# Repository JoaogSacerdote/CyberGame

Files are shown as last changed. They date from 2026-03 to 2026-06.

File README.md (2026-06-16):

# CyberGame — Console Educativo de Cibersegurança

> Console portátil de jogo educativo que ensina conceitos de segurança digital
> (senhas, backup, ransomware, DDoS) por meio de mecânicas de RPG top-down 2D
> em pixel art. Hardware próprio baseado em ESP32-S3.

**Versão:** 0.1.0 · **Plataforma:** ESP32-S3 + ESP-IDF 6.0 + LVGL 9.x

---

## Sobre o projeto

O CyberGame é um console portátil construído em hardware próprio. O jogador
assume o papel de um profissional de TI em uma empresa e precisa reagir a
ameaças digitais (ransomware, DDoS, propagação de malware) aplicando as
contramedidas corretas — backup, isolamento de rede, gestão de senhas — dentro
do tempo de um "expediente". O objetivo é ensinar os pilares de segurança da
informação de forma prática e lúdica.

---

## Hardware

| Componente | Descrição |
|---|---|
| **MCU** | ESP32-S3 (N16R8) com 8 MB PSRAM Octal @ 40 MHz |
| **Display** | LCD SPI ST7796, 480×320 px, backlight via transistor (GPIO 42) |
| **Entrada** | Joystick analógico (ADC) + 4 botões (A / B / X / Y) |
| **Armazenamento** | Cartão microSD via SPI (assets e layouts de sala) |
| **LEDs** | 3× WS2812 RGB (indicadores de tarefa) |
| **NFC** | Leitor PN532 via I²C (cartas físicas liberam ações no jogo) |

O pinout completo está em [`hardware/PINOUT.md`](hardware/PINOUT.md). Esquemas
elétricos e arquivos de PCB ficam em [`hardware/`](hardware/).

---

## Arquitetura do firmware

```
main/                 boot, banner e inicialização da engine
components/
  engine/             loop principal, init dos HALs, task LVGL
  hardware/           HALs: display, botões, joystick, PMU, SD, NFC
  hal_bridge/         ponte hardware → LVGL (HALs não conhecem LVGL)
  assets/             carregador de assets (cache load-once) e diálogos
  asset_store/        camada de arquivos sobre o storage
  entity/             pool de entidades, movimento, Y-sort, debug overlay
  ui/                 telas: splash, menu, recepção, empresa, HUD, pause
  fsm/                máquina de estados do jogo
  gamestate/          estado persistente (progresso, tarefas)
  recovery/           modo de recuperação via USB CDC
```

**Convenções principais:**
- HALs (`components/hardware/*.h`) nunca incluem LVGL — a integração fica em `hal_bridge/`.
- Atualizações de UI passam por *diff-gate* e usam `lv_timer_create` (não tasks FreeRTOS).
- Sistema de entidades com pivô *bottom-center*; ordenação por Y-sort.

---

## Compilando e gravando

Requer [ESP-IDF 6.0](https://docs.espressif.com/projects/esp-idf/) instalado.

```powershell
# Ativar o ambiente do ESP-IDF (PowerShell)
. "C:\esp\v6.0\esp-idf\export.ps1"

# Build + gravação + monitor serial
idf.py build flash monitor
```

> Se o build falhar com erros de paths/MinGW, apague a pasta `build/` e
> recompile.

---

## Pipeline de assets

Os sprites são desenhados como PNGs individuais e convertidos em blobs RGB565
prontos para o ESP32, gravados no cartão microSD. Os scripts ficam em
[`tools/`](tools/):

```powershell
# Gera os IDs de asset a partir do registry
python tools/gen_asset_ids.py

# Converte sprites + layouts para sdcard/assets/
python tools/build_sd_assets.py

# Copiar o conteúdo de sdcard/assets/ para o cartão microSD
```

A fonte de verdade dos assets é [`assets/asset_registry.json`](assets/asset_registry.json)
(nome → ID → arquivo). Os layouts de sala (posições das entidades) ficam em
`assets/layout/`.

---

## Estrutura do repositório

```
main/            ponto de entrada do firmware
components/      componentes do firmware (engine, HALs, UI, etc.)
assets/          sprites, diálogos, layouts e registry de assets
tools/           scripts do pipeline de assets e utilitários
hardware/        pinout, esquemas elétricos e arquivos de PCB
pc_simulator/    simulador das telas em PC (LVGL + SDL)
simulation/      simulação em PC (LVGL + SDL2)
test/            testes
```

---

## Simulador em PC

As telas de UI podem ser testadas no computador sem o hardware. Veja
[`pc_simulator/README.md`](pc_simulator/README.md) e
[`simulation/`](simulation/) para detalhes de compilação com LVGL + SDL.

---

## Status

Em desenvolvimento ativo (versão 0.1.0). Já funcionando: HALs de display,
botões, joystick, PMU e SD; engine com loop LVGL; pipeline de assets; sistema
de entidades com Y-sort; salas de recepção e empresa; FSM de estados.

---

## Autoria

Projeto desenvolvido por:

| Autor | E-mail | GitHub |
|---|---|---|
| **João Gabriel** | `joaog.souza2002@gmail.com` | [@JoaogSacerdote](https://github.com/JoaogSacerdote) |
| **Klayveer Silva** | `silvaklayveer@gmail.com` | [@Klayveer](https://github.com/Klayveer) |
| **Caio Godoy** | `caiogodoy05@gmail.com` | [@caiocodes](https://github.com/caiocodes) |

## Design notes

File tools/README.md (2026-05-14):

# tools/

Utilitarios de PC para conversar com o CyberGame em modo recovery via USB CDC.

## Pre-requisitos

```
pip install pyserial
```

## Como entrar em modo recovery no aparelho

1. Aparelho desligado.
2. Segure **PWR + REC** simultaneamente por 2 segundos.
3. Solte. Aparelho boota e enumera **uma porta serial nova** no PC (alem da porta UART/JTAG existente). Tipicamente aparece como "USB Serial Device" no Device Manager.

## Scripts

### test_ping.py

Smoke-test do protocolo de recovery (Fase 3). Monta um frame binario `CMD_PING`,
envia, e valida o `RESP_PONG` de volta — confirma enquadramento, CRC32 e o
round-trip USB CDC. O contrato do protocolo esta em
`components/recovery/include/recovery_proto.h`.

```
python test_ping.py COM21
```

Saidas possiveis:

| Saida | Significado |
|---|---|
| `OK — framing, CRC e round-trip USB CDC validados.` | Protocolo funcionando ponta a ponta |
| `FAIL: timeout esperando SOF ...` | ESP nao respondeu (2s) — checar se esta em recovery e se e a porta CDC certa |
| `FAIL: CRC do frame nao bate ...` | Resposta corrompida na linha — ruido ou bug de enquadramento |
| `FAIL: versao do firmware (vX) != script` | Firmware e script com versoes de protocolo diferentes — recompilar/atualizar |
| `<- NACK (esp_err_t = N)` | ESP rejeitou o comando — ver codigo de erro |
| `FAIL: nao consegui abrir a porta: ...` | Porta errada / outro programa segurando — checar Device Manager |

### asset_uploader.py

Gerencia os assets na NAND do aparelho via USB CDC. Subcomandos:

```
python tools/asset_uploader.py <PORTA> ping                        # PING -> PONG
python tools/asset_uploader.py <PORTA> ls                          # lista assets na NAND
python tools/asset_uploader.py <PORTA> upload                      # grava TODOS os assets do registry
python tools/asset_uploader.py <PORTA> upload rec_paredes          # grava so um asset
python tools/asset_uploader.py <PORTA> download sprite 0 piso.bin  # baixa o blob cru
python tools/asset_uploader.py <PORTA> download sprite 0 piso.png --png  # baixa e decodifica
python tools/asset_uploader.py <PORTA> erase sprite                # apaga uma categoria
python tools/asset_uploader.py <PORTA> reset                       # factory reset (tudo)
python tools/asset_uploader.py <PORTA> selftest                    # validacao fisica do NAND
```

`<tipo>` = `sprite` | `font` | `sound`. O `upload` e o `download --png` precisam
do Pillow (`pip install pillow`).

### recovery_protocol.py

Modulo (nao roda direto) com a camada de transporte do protocolo de recovery —
framing, CRC32 e a classe `RecoveryClient`. Espelha
`components/recovery/include/recovery_proto.h`. Importado por `test_ping.py` e
`asset_uploader.py`; fonte unica da logica de protocolo no lado PC.

### asset_codec.py

Modulo (nao roda direto) com o pipeline de imagem PNG -> RGB565/RGB565A8.
Espelha `components/assets/include/asset_blob.h`. Fonte unica do encoder —
usado tanto pelo `asset_uploader.py` (blobs da NAND) quanto pelo
`convert_assets.py` (arrays C embarcados, legado ate a Fase 6).

### gen_asset_ids.py

Gera `components/assets/include/asset_ids.h` a partir do registry — os
simbolos `ASSET_*` que o firmware usa com `asset_loader_load()`. Rode sempre
que mexer no `asset_registry.json`:

```
python tools/gen_asset_ids.py
```

## assets/asset_registry.json

Fonte unica de verdade dos assets: mapeia cada PNG renderizavel para um
`(type, id, name)` estavel. Consumido pelo `asset_uploader.py upload` (grava
na NAND) e pelo `gen_asset_ids.py` (gera os simbolos do firmware).
Arquivos `*_NULL.png` (mascaras de area/colisao) **nao** entram aqui.

## Identificando a porta CDC

No Windows: abre Device Manager → Portas (COM e LPT). Quando o aparelho entra em recovery, aparece uma porta nova. Geralmente "USB Serial Device (COMxx)".

Existem **duas portas** quando o aparelho esta em recovery:
- **Porta JTAG/UART** (para `idf.py monitor`) — aparece sempre quando aparelho ligado
- **Porta CDC** (para esses scripts) — so aparece em modo recovery

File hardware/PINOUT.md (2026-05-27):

# Pinout do CyberGame ESP32-S3

> Fonte de verdade: `components/hardware/include/board_pins.h`
> Última atualização: 2026-05-27

## Joystick analógico (ADC1)

| GPIO | Função | Notas |
|---|---|---|
| 1 | JOY_X | ADC1_CH0 |
| 2 | JOY_Y | ADC1_CH1 |

## Botões frontais

| GPIO | Função | Notas |
|---|---|---|
| 9 | BTN_A | input pull-up |
| 10 | BTN_X | input pull-up |
| 11 | BTN_B | input pull-up |
| 12 | BTN_Y | input pull-up |
| 13 | BTN_START | input pull-up; **dual-use com PMU_REC** |

## PMU (Power Management Unit)

| GPIO | Função | Notas |
|---|---|---|
| 13 | PMU_REC | recovery button; **mesmo pino do BTN_START** (PMU lê no boot, button_hal lê após) |
| 14 | PMU_PWR | power button + EXT0 wakeup |

## NFC PN532 (I2C)

| GPIO | Função | Notas |
|---|---|---|
| 4 | NFC_SCL | I2C clock |
| 39 | NFC_SDA | I2C data |
| 40 | NFC_IRQ | interrupt out |

## Display ST7796 (SPI2_HOST)

| GPIO | Função | Notas |
|---|---|---|
| 5 | DISP_CS | chip select |
| 6 | DISP_RST | reset ativo-baixo |
| 7 | DISP_DC | data/command select |
| 15 | DISP_MOSI | SPI MOSI; **compartilhado com NAND** |
| 16 | DISP_SCK | SPI clock; **compartilhado com NAND** |
| 17 | DISP_BL | backlight (LEDC PWM 10 kHz) |
| 42 | DISP_PWR_EN | NPN driver: 1=liga VCC, 0=corta |

## Storage NAND W25N01GV (SPI2_HOST, compartilha bus com display)

| GPIO | Função | Notas |
|---|---|---|
| 15 | NAND_MOSI | **mesmo pino do DISP_MOSI** |
| 16 | NAND_SCK | **mesmo pino do DISP_SCK** |
| 18 | NAND_MISO | exclusivo NAND |
| 41 | NAND_CS | chip select |

## Resumo por GPIO

| GPIO | Quem usa | Subsistema |
|---|---|---|
| 1 | JOY_X | Joystick |
| 2 | JOY_Y | Joystick |
| 4 | NFC_SCL | NFC |
| 5 | DISP_CS | Display |
| 6 | DISP_RST | Display |
| 7 | DISP_DC | Display |
| 9 | BTN_A | Botões |
| 10 | BTN_X | Botões |
| 11 | BTN_B | Botões |
| 12 | BTN_Y | Botões |
| 13 | BTN_START + PMU_REC | Botões + PMU (dual-use) |
| 14 | PMU_PWR | PMU |
| 15 | DISP_MOSI + NAND_MOSI | SPI2 (compartilhado) |
| 16 | DISP_SCK + NAND_SCK | SPI2 (compartilhado) |
| 17 | DISP_BL | Display |
| 18 | NAND_MISO | NAND |
| 39 | NFC_SDA | NFC |
| 40 | NFC_IRQ | NFC |
| 41 | NAND_CS | NAND |
| 42 | DISP_PWR_EN | Display |

## Invariantes garantidos por `_Static_assert` em board_pins.h

- `BOARD_PIN_BTN_START == BOARD_PIN_PMU_REC` (dual-use deliberado)
- `BOARD_PIN_NAND_MOSI == BOARD_PIN_DISP_MOSI` (bus SPI2 compartilhado)
- `BOARD_PIN_NAND_SCK == BOARD_PIN_DISP_SCK` (idem)

Mudar pino em `board_pins.h` sem respeitar esses invariantes quebra o build.

## Notas de hardware

- **Protoboard atual** (PCB descartada momentaneamente em 2026-05-27).
- **Bus SPI2 compartilhado**: Display é dono (`spi_bus_initialize`); NAND tolera `ESP_ERR_INVALID_STATE` e usa `spi_bus_add_device`.
- **Backlight do display** via LEDC channel 0, timer 0, duty 13-bit, freq 10 kHz.
- **Brownout Detector** ativo no nível 7 (max) — ver `sdkconfig` `CONFIG_BROWNOUT_DET_LVL=7`.
- Esquemático KiCad em `hardware/esquematico/` (referência visual).

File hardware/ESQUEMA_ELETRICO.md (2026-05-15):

# CyberGame — Informações para o Esquema Elétrico

> Console portátil **CyberSec: Network Defender**.
> Documento de referência para desenhar o schematic (KiCad em `hardware/CyberGame_kicad/`).
> Pinout confirmado pelo usuário; última revisão de GPIO em 2026-05-12.

---

## 1. Componentes principais

| Bloco | Componente | Interface | Tensão |
|---|---|---|---|
| MCU | **ESP32-S3 N16R8** (16 MB Flash, 8 MB PSRAM Octal) | — | 3V3 |
| Asset storage | **NAND SPI Winbond W25N01GV** (1 Gbit / 128 MB) | SPI | 3V3 |
| Display | **LCD TFT 4.0" 480x320**, controlador **ST7796S** | SPI 4-fios | 3V3 lógica + VCC painel |
| NFC | **PN532** (módulo) | I²C | 3V3 |
| Input analógico | Joystick analógico dual-axis (modelo PSP slim, **sem botão SEL**) | 2x ADC | 3V3 |
| Input digital | 4x push-button A/B/X/Y + REC/START + PWR | GPIO | 3V3 |
| Áudio | Buzzer **passivo** (piezo) | PWM | 3V3 |
| LEDs | **3x WS2812** endereçáveis | RMT 1-wire | 5V (ou 3V3, ver §7) |
| Energia | Bateria Li-Po + carregador **TP4056** + regulador 3V3 | — | 3.7–4.2 V → 3V3 |

⚠️ **GPIOs 26–37 são proibidos** — usados internamente pela PSRAM Octal. Não rotear nada neles.

---

## 2. Pinout definitivo do ESP32-S3

| GPIO | Função | Bloco | Observações |
|---|---|---|---|
| 1  | Joystick eixo X | ADC1_CH0 | Entrada analógica |
| 2  | Joystick eixo Y | ADC1_CH1 | Entrada analógica |
| 3  | **REC + START** (dual-use) | Botão | Boot: PMU lê como REC (combo PWR+REC = recovery). Pós-boot: BTN_START (pause). Ativo em nível baixo. |
| 4  | **PWR** | Botão | Botão de power/sleep. Fonte de wake `ext0` do Deep Sleep. Ativo em nível baixo. |
| 5  | NFC **SDA** | I²C | Precisa pull-up (ver §6) |
| 6  | NFC **SCL** | I²C | Precisa pull-up (ver §6) |
| 7  | **SPI MOSI** | SPI | **Compartilhado** Display + NAND |
| 8  | **SPI SCK** | SPI | **Compartilhado** Display + NAND |
| 9  | **MISO** | SPI | Usado pela NAND (leitura). Display é write-only. |
| 10 | NAND **CS** | SPI | Chip-select da NAND |
| 11 | Botão **A** | Botão | Confirmar / Interagir. Ativo em nível baixo. |
| 12 | Botão **B** | Botão | Cancelar / Voltar. Ativo em nível baixo. |
| 13 | Botão **X** | Botão | Dashboard do Analista. Ativo em nível baixo. |
| 14 | Botão **Y** | Botão | Abrir Terminal. Ativo em nível baixo. |
| 15 | **Buzzer** | PWM (LEDC) | Piezo passivo, acionamento direto. **Não** é strapping pin — escolha segura. |
| 16 | NFC **IRQ** | GPIO in | Interrupção do PN532 |
| 17 | Display **CS** | SPI | Chip-select do display |
| 18 | Display **DC** | GPIO out | Data/Command do ST7796S |
| 21 | Display **RST** | GPIO out | Reset do ST7796S |
| 38 | Display **BL** (LED do painel) | PWM (LEDC) | Pino LED/backlight do painel — controle de brilho |
| 42 | Display **VCC enable** | GPIO out | Liga/corta VCC do painel via transistor **NPN**. **1 = LIGA, 0 = CORTA** (ver §5) |
| 45 | *(livre)* | — | **Strapping pin** (VDD_SPI voltage) — deixar livre / não conectar. |
| 48 | **WS2812 Data** | RMT | Linha de dados dos 3 LEDs em cadeia |

**GPIOs livres / não usados:** 45 (strapping — não usar). Os demais não listados estão livres exceto 26–37 (PSRAM).

---

## 3. Barramento SPI (compartilhado: Display + NAND)

```
ESP32-S3  GPIO7  (MOSI) ──┬── ST7796S SDA/MOSI
                          └── W25N01GV DI (IO0)
ESP32-S3  GPIO8  (SCK)  ──┬── ST7796S SCK
                          └── W25N01GV CLK
ESP32-S3  GPIO9  (MISO) ───── W25N01GV DO (IO1)        (display não usa MISO)
ESP32-S3  GPIO17 (CS)   ───── ST7796S CS
ESP32-S3  GPIO10 (CS)   ───── W25N01GV CS
```

- Dois dispositivos, **um barramento**, **CS independentes** — só um ativo por vez.
- Display roda a 40 MHz; NAND a **50 MHz** (validado com `selftest`). A NAND suporta até ~104 MHz. O barramento é seguro pela seleção de CS.
- **Pull-up de ~10 kΩ em cada CS** (GPIO10 e GPIO17) para 3V3 — evita seleção espúria durante boot/reset, quando os GPIOs estão em alta impedância.
- Manter as trilhas MOSI/SCK curtas e de comprimento parecido; se possível, resistor série de 22–33 Ω em MOSI e SCK próximos ao ESP para conter ringing.
- W25N01GV: amarrar **WP#** e **HOLD#** a 3V3 (não usados no modo SPI single).

---

## 4. Barramento I²C (NFC PN532)

```
ESP32-S3  GPIO5 (SDA) ──┬── PN532 SDA ──── [4.7 kΩ] ── 3V3
ESP32-S3  GPIO6 (SCL) ──┬── PN532 SCL ──── [4.7 kΩ] ── 3V3
ESP32-S3  GPIO16      ───── PN532 IRQ
                          PN532 VCC ── 3V3
                          PN532 GND ── GND
```

- **Pull-ups obrigatórios**: 4.7 kΩ em SDA e SCL para 3V3 (se o módulo PN532 já trouxer pull-ups na placa, **não duplicar** — verificar antes).
- Confirmar que o módulo PN532 está com os jumpers/switch em modo **I²C** (muitos vêm em HSU/SPI de fábrica).
- IRQ é entrada — o firmware energiza o campo RF só quando necessário (estado de terminal). RST do PN532 pode ficar em 3V3 fixo se não for usado.

---

## 5. Display ST7796S — alimentação e controle

**Lógica (3V3):** CS=GPIO17, DC=GPIO18, RST=GPIO21, SCK=GPIO8, MOSI=GPIO7. MISO do display não é usado.

**Resumo da fiação de energia do display (confirmado pelo usuário):**
- **GPIO42** → base do transistor **NPN** → chave do **VCC do painel**.
- **GPIO38** → pino **LED/backlight** do painel (controle de brilho via PWM).

**VCC do painel — chave via GPIO42:**
- O GPIO 42 controla um **transistor NPN** que atua como *driver de gate* de uma chave high-side (P-MOSFET) que liga/desliga o **VCC do painel**.
- Polaridade lógica: **GPIO42 = 1 → painel LIGADO**; **GPIO42 = 0 → painel DESLIGADO**.
- Topologia recomendada:
  ```
  GPIO42 ──[1 kΩ]── base NPN ;  emissor NPN → GND
  coletor NPN ──┬── gate do P-MOSFET high-side
                └──[100 kΩ]── source/3V3 (pull-up do gate)
  P-MOSFET: source → 3V3 (ou rail do painel) ; dreno → VCC do display
  ```
  Com GPIO42=1 o NPN conduz, puxa o gate do P-MOSFET para baixo, e o P-MOSFET liga o VCC.
- ⚠️ O código de referência em `CONSULTA/display_hal.c` ainda usa lógica **PNP antiga** (0=liga). O hardware atual é **NPN (1=liga)** — substituído em 2026-05-10.
- Em boot: setar GPIO42=1 **antes** de iniciar o SPI e aguardar ~50 ms de estabilização.

**Backlight (BL = GPIO38):**
- Controlado por PWM (LEDC). Se o LED de backlight do painel exigir mais corrente do que um GPIO entrega com segurança (>20 mA), inserir um **transistor/MOSFET** para acionar o backlight, com o GPIO38 na base/gate. Verificar a corrente do backlight no datasheet do módulo do painel.

**Decoupling:** 100 nF + 10 µF próximos da alimentação do módulo do display.

---

## 6. Entradas digitais (botões)

6 botões momentâneos, todos **ativo-baixo** (botão entre GPIO e GND):

```
GPIO ──┬── botão ── GND
       └──[pull-up]── 3V3
```

- O ESP32-S3 tem **pull-up interno** — pode dispensar resistor externo. Para robustez (ruído/cabos longos), opcional pull-up externo de 10 kΩ.
- Debounce é feito em **firmware** (`button_hal`: ISR + timer). Opcional capacitor de 100 nF em paralelo com cada botão para debounce em hardware.
- Botões: A=11, B=12, X=13, Y=14, REC/START=3, PWR=4.
- **GPIO3 e GPIO4** são lidos pela PMU no boot (combo PWR+REC = modo recovery). GPIO4 também é a fonte de wake `ext0` do Deep Sleep — garantir que em repouso o pino fique em nível **alto** (pull-up) e o botão leve a **baixo**.

---

## 7. WS2812 (3 LEDs endereçáveis)

```
ESP32-S3 GPIO48 ──[330–470 Ω]── DIN do LED1 ── DOUT→DIN LED2 ── DOUT→DIN LED3
LEDs VCC ── 5V (ou 3V3, ver nota) ;  LEDs GND ── GND
Capacitor 1000 µF entre VCC e GND dos LEDs, próximo ao primeiro LED
```

- **Resistor série 330–470 Ω** na linha de dados, junto ao GPIO48.
- **Capacitor de bulk 1000 µF** (≥6.3 V) nos terminais de alimentação da fita/LEDs.
- **Alimentação: 3V3** (decisão confirmada pelo usuário). Os 3 LEDs são alimentados pelo próprio rail 3V3 do sistema — **sem level shifter**. Com VCC=3V3 o nível lógico "1" do ESP (3.3 V) atende o WS2812 sem margem problemática. Brilho levemente menor que a 5V, aceitável para 3 LEDs de status.
- Função: LED1 = tarefa verde pendente, LED2 = tarefa amarela, LED3 = alerta de ataque (lógica composta de escalada — ver `game_logic_decisions`).

---

## 8. Buzzer (áudio)

```
GPIO15 ──[resistor série opcional 100 Ω]── piezo ── GND
```

- **Pino escolhido: GPIO15.** Motivo: está livre, **não é strapping pin** e suporta PWM via LEDC. Substitui o GPIO45 sugerido antes — GPIO45 é strapping pin (VDD_SPI) e foi liberado.
- Buzzer **passivo** acionado por **PWM (LEDC)** direto do GPIO15 — **sem transistor** nesta versão (decisão de projeto).
- Só SFX, sem música de fundo. Mute = duty 0%.
- Se o volume ficar baixo, evoluir depois para um transistor + indutor/driver — mas **não** está no MVP.

---

## 9. Joystick analógico

Joystick dual-axis com 2 potenciômetros (um por eixo). **Sem botão SEL.**

```
Pot eixo X:  terminal1 → 3V3 ;  terminal2 → GND ;  wiper → GPIO1 (ADC1_CH0)
Pot eixo Y:  terminal1 → 3V3 ;  terminal2 → GND ;  wiper → GPIO2 (ADC1_CH1)
```

- Capacitor de **10–100 nF** de cada wiper para GND — filtra ruído do ADC.
- Usar **ADC1** (GPIO1/GPIO2 são ADC1) — ADC2 conflita com o Wi-Fi/rádio.
- Firmware faz média móvel (MA8) + deadzone 5% + calibração; mesmo assim o filtro RC em hardware ajuda.

---

## 10. Subsistema de energia

```
Li-Po 3.7V ──→ TP4056 (carga + proteção) ──→ Regulador 3V3 ──→ rail 3V3 do sistema
                    ↑
                USB 5V (carga)
```

- **TP4056**: módulo de carga Li-Po. Usar preferencialmente a versão **com proteção** (DW01 + FS8205) contra sobre-descarga/sobre-corrente.
- **Regulador 3V3**: a bateria entrega 3.0–4.2 V; o ESP32-S3 e todos os periféricos rodam em **3V3 regulado**. Opções:
  - **LDO** (ex.: AMS1117-3.3, ME6211, RT9013) — simples; escolher um que aguente o pico de corrente do ESP-S3 em TX (~500 mA de margem). O AMS1117 tem dropout alto (~1.1 V) — com a bateria abaixo de ~3.4 V o rail cai; preferir um LDO **low-dropout** (ME6211/RT9013, dropout ~0.25 V).
  - **Buck** se quiser maximizar autonomia.
- **Decoupling do ESP32-S3**: 100 nF em cada pino VDD + um bulk de 22–47 µF próximo ao módulo. Seguir as recomendações do datasheet do módulo ESP32-S3.
- **PWR / power management**: não há latch de hardware no MVP — o desligamento é via **Deep Sleep** do ESP, com wake por `ext0` no GPIO4. O botão PWR (GPIO4) só precisa de botão→GND + pull-up. (Se quiser desligamento real de hardware no futuro, adicionar um circuito de soft-latch com MOSFET.)
- Estimar a corrente de pico: ESP-S3 + backlight do display + 3 WS2812 podem somar facilmente >400 mA — dimensionar regulador e trilhas de alimentação para isso.

---

## 11. Checklist para o schematic

- [ ] ESP32-S3 N16R8 com decoupling completo (datasheet do módulo) e EN com RC de reset.
- [ ] Strapping pins: GPIO0 (boot), GPIO45/46 — **deixar livres** (GPIO45 não é mais usado pelo buzzer; buzzer migrou para GPIO15). GPIO3 também é strapping mas é uso intencional (REC).
- [ ] GPIOs 26–37 livres (PSRAM Octal).
- [ ] Pull-ups: I²C SDA/SCL (4.7k), SPI CS x2 (10k), botões (interno ou 10k).
- [ ] Barramento SPI com CS independentes; WP#/HOLD# da NAND em 3V3.
- [ ] Transistor NPN + P-MOSFET do VCC do display (GPIO42, lógica 1=liga).
- [ ] Resistor série + capacitor bulk dos WS2812; decidir alimentação 3V3.
- [ ] Filtro RC nos wibers do joystick; usar ADC1.
- [ ] TP4056 (com proteção) + regulador 3V3 low-dropout dimensionado para o pico.
- [ ] Conectores: USB (carga + dados/recovery CDC), bateria, display (FPC/header), módulo NFC, módulo joystick.
- [ ] Pontos de teste em 3V3, GND, MOSI, SCK, SDA, SCL.

---

## 12. Pendências / decisões em aberto de hardware

- **Backlight do display**: GPIO38 vai no pino LED do painel. Confirmar a corrente desse LED — define se GPIO38 aciona direto ou via MOSFET.
- **PN532**: confirmar se o módulo já tem pull-ups I²C na placa (para não duplicar) e se o modo está em I²C.
- Sem latch de power em hardware — desligamento só por Deep Sleep. Reavaliar se for requisito.

### Resolvidos
- ✅ **Buzzer**: GPIO15 (livre, não-strapping). GPIO45 liberado.
- ✅ **WS2812**: alimentação 3V3, sem level shifter.
- ✅ **GPIO42/38**: 42 = NPN do VCC do painel; 38 = pino LED/backlight. Lógica NPN (1=liga).

---

*Fontes: `hardware/PINOUT`, memória de projeto `project_hardware`, `game_logic_decisions` (RESPOSTAS.txt 2026-05-12), e código atual dos HALs em `components/hardware/`.*

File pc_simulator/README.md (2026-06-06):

# CyberSim — Simulador PC do firmware

Roda os mesmos `components/ui/screen_*.c` do firmware numa janela SDL no PC,
sem precisar flashar o aparelho a cada mudança visual.

## Estado atual

**Etapa 1** — Prova de conceito: SDL2 + LVGL 9.3.0 funcionando.
Ainda não integra os components do firmware.

| Etapa | Status |
|---|---|
| 1. Setup SDL + LVGL | ✅ |
| 2. HALs fake (joystick/botões via teclado) + FreeRTOS shim| ⏳ |
| 3. Storage fake (lê `nand.bin`) + asset_store + dialog | ⏳ |
| 4. Engine + FSM + telas do firmware compilando | ⏳ |

## Pré-requisitos

- MSYS2 instalado em `C:\msys64` com `mingw64/bin` (gcc, cmake, ninja, SDL2)
- Pacote: `pacman -S mingw-w64-x86_64-SDL2`

## Compilar e rodar

```bat
COMPILAR.bat
RODAR.bat
```

Resultado esperado da Etapa 1: janela 480×320 com fundo escuro e mensagem
"CyberSim — Etapa 1: pronto". Feche pra encerrar.

## Estrutura (futura)

```
pc_simulator/
  CMakeLists.txt           # build CMake usando SDL2 + MinGW
  main.c                   # app_main equivalente
  lv_conf.h                # config LVGL pra SDL (LV_COLOR_DEPTH=32, LV_USE_SDL=1)
  esp_idf_shim/            # esp_log, esp_err, esp_check, esp_heap_caps → stubs
  freertos_shim/           # xTaskCreate, xQueue, vTaskDelay → pthread
  hal_fake/                # display/joystick/button/nfc/pmu/storage fakes
  tools/                   # gerar nand.bin a partir do asset_registry.json
```

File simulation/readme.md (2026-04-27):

# CyberSec: Network Defender — Simulador LVGL (PC)

Simulador de PC do jogo embarcado **CyberSec: Network Defender**, escrito em C usando **LVGL 9.x**
renderizado via **SDL2**. Permite rodar e testar o jogo completo no Windows sem nenhum hardware real.

- Janela: **480 × 320 px** (equivalente ao display ILI9341 do ESP32-S3)
- Build: **CMake + MinGW GCC** via MSYS2
- Dependências externas: apenas SDL2 (já incluída no MSYS2)

---

## Estrutura do Projeto

```
simulation/
├── readme.md                       ← este arquivo
├── img/                            ← screenshots de referência (UI mockups)
└── lv_port_pc_eclipse/             ← projeto CMake para PC
    ├── main.c                      ← entry point: inicializa SDL + LVGL, chama cybersec_start()
    ├── cybersec_game.h             ← API pública do jogo
    ├── cybersec_game.c             ← motor completo (UI, FSM, lógica, ~1500 linhas)
    ├── lv_conf.h                   ← configuração LVGL (fontes, cores, resolução)
    ├── CMakeLists.txt              ← build system
    ├── COMPILAR.bat                ← compila o projeto (git submodule + cmake)
    ├── RODAR.bat                   ← inicia o executável com DLLs corretas
    ├── lvgl/                       ← biblioteca LVGL 9.3 (clonada pelo COMPILAR.bat)
    └── bin/
        └── main.exe                ← executável final (gerado após build)
```

---

## Pré-requisitos

| Ferramenta | Versão mínima | Observação |
|---|---|---|
| Windows | 10 / 11 | — |
| Git | qualquer | Para clonar o submodule LVGL |
| MSYS2 (GCC + CMake + SDL2) | — | Instalar antes de compilar |

### Instalar MSYS2 (apenas na primeira vez)

```bat
winget install --id MSYS2.MSYS2 --accept-package-agreements --accept-source-agreements
```

### Instalar GCC, CMake e SDL2 (apenas na primeira vez)

```bat
C:\msys64\usr\bin\pacman.exe -S --noconfirm --needed ^
  mingw-w64-x86_64-gcc ^
  mingw-w64-x86_64-cmake ^
  mingw-w64-x86_64-SDL2 ^
  mingw-w64-x86_64-make
```

---

## Como Compilar e Rodar

Navegue até `simulation/lv_port_pc_eclipse/` e:

### Primeira vez (ou após alterar o código)

Dê **duplo clique** em `COMPILAR.bat`. O script:

1. Verifica GCC/CMake em `C:\msys64\mingw64\bin\`
2. Clona o submodule LVGL via `git submodule update --init --recursive`
3. Executa `cmake -B build -S . -G "MinGW Makefiles"`
4. Compila com `cmake --build build --parallel 4`
5. Gera `bin/main.exe`

### Rodar

Dê **duplo clique** em `RODAR.bat`. A janela **480×320** abre imediatamente.

### Resumo rápido

```
1ª vez:  COMPILAR.bat  →  RODAR.bat
Demais:  RODAR.bat
Após editar código:  COMPILAR.bat  →  RODAR.bat
```

---

## Fluxo do Jogo

```
Tela Inicial
    │  [A] para iniciar
    ▼
Tutorial (8 passos)
    │  [A] para avançar cada diálogo
    ▼
Jogo (08:00 → 18:00)
    │  Resolver incidentes, mover entre salas
    ▼
Vitória (18:00 com integridade > 0)
ou Derrota (integridade chegou a 0)
    │  [R] para reiniciar
    ▼
  Tela Inicial
```

---

## Controles

| Tecla | Ação |
|---|---|
| `↑` `↓` `←` `→` | Mover o personagem pelo escritório |
| `A` ou `SPACE` | Confirmar diálogo de tutorial / Abrir e resolver incidente verde ou amarelo |
| `N` | Scan NFC — abre e resolve incidente vermelho (Ransomware) |
| `R` | Reiniciar o jogo a qualquer momento |

### Resolver um incidente

1. Mova o personagem **até ficar próximo** da bolha colorida no mapa (raio ~50 px).
2. Pressione `A` (incidentes verdes ou amarelos) ou `N` (ransomware vermelho).
3. Um **diálogo de detalhe** abre com informações da vulnerabilidade.
4. Pressione `A` ou `N` novamente para confirmar a resolução.

---

## Mecânicas do Jogo

### Mapa — Dois Andares

O jogo possui dois ambientes com layout pixel-art:

```
┌─────────────────────────────────────┐
│         Recepção (Sala 1)           │  ── porta direita ──►  Escritório
│  (prateleiras, tapete, sofá, rack)  │
└─────────────────────────────────────┘

┌─────────────────────────────────────┐
│         Escritório (Sala 2)         │  ◄── porta esquerda ── Recepção
│  (mesas, PCs, impressoras, plantas) │
└─────────────────────────────────────┘
```

**Transição entre salas:** caminhe até a **borda lateral** (indicador `► 2` ou `◄ 1`).  
O personagem aparece na porta oposta da outra sala.

---

### Incidentes (Bolhas Coloridas)

A cada 9–16 segundos, um incidente surge em ponto fixo de uma sala aleatória:

| Ícone | Cor | Tipo | Drenagem | Resolução | Pontos |
|---|---|---|---|---|---|
| `?` | Verde | Tarefa de prevenção | 1 HP/2s | `A` / `SPACE` | +15 |
| `!` | Amarelo | Anomalia suspeita | 4 HP/2s | `A` / `SPACE` | +15 |
| `X` | Vermelho | Ransomware ativo | 10 HP/2s | `N` (NFC scan) | +30 |

Máximo de **4 incidentes simultâneos** em toda a empresa.

---

### Sistema de Integridade da Rede

- Exibida no HUD como barra colorida e percentual.
- Calculada a partir dos HP dos incidentes ativos:
  - Sem incidentes ativos → **100%**
  - Com incidentes → proporcional ao HP médio restante
- Cor da barra: verde (>60%), amarelo (>30%), vermelho (≤30%).
- **Integridade = 0% → Derrota imediata.**

---

### Relógio do Jogo

- **3 minutos reais** = expediente completo das **08:00 às 18:00** (10h de jogo).
- O relógio aparece no canto superior esquerdo do HUD.
- Chegar às **18:00** com integridade > 0 = **Vitória**.

---

### Tutorial

Ao iniciar, o NPC guia apresenta **8 diálogos** explicando:

1. Boas-vindas e contexto do jogo
2. Controles de movimento
3. Incidentes verdes (prevenção)
4. Incidentes amarelos (anomalias)
5. Incidentes vermelhos (ransomware)
6. Como interagir com incidentes
7. Consequências de ignorar incidentes
8. Dica sobre explorar as duas salas

Pressione `A` para avançar cada passo.

---

## Arquitetura do Código

```
main.c
├── hal_init(480, 320)               — cria display SDL 480×320, registra driver LVGL
├── SDL_AddEventWatch(sdl_key_watch) — hook de teclado SDL → cybersec_sdl_key_event()
└── loop: lv_timer_handler() + SDL_Delay(5)

cybersec_start()                     — inicializa estado global, cria tela inicial
    │  [A]
    ▼
create_hud()                         — barra HUD: relógio, REDE: [barra], status
build_room1() / build_room2()        — layout pixel-art com lv_obj (mk_rect calls)
create_player()                      — personagem: head (skin+hair) + body (camisa)
show_tutorial_step()                 — overlay com portrait NPC + texto + indicador [A] N/8
    │  após step 8
    ▼
start_timers()
    ├── tmr_move_cb   (16 ms)   — move personagem, detecta transição de sala
    ├── tmr_clock_cb  (500 ms)  — avança relógio do jogo, checa vitória às 18:00
    ├── tmr_event_cb  (9–16 s)  — sorteia sala + tipo de incidente, cria bolha colorida
    └── tmr_drain_cb  (2 s)     — drena HP dos incidentes ativos, checa derrota

cybersec_sdl_key_event(key, pressed)
    ├── UP/DOWN/LEFT/RIGHT  → g_keys.* lidas por tmr_move_cb
    ├── A / SPACE           → avança tutorial ou abre/resolve dialog de incidente
    ├── N                   → abre/resolve dialog de ransomware (NFC)
    └── R                   → do_restart() — limpa tudo e reinicia
```

---

## Integração com Firmware ESP32 (Wokwi / Hardware Real)

O motor do jogo (`cybersec_game.c`) **não depende de SDL**, apenas de LVGL.  
Para rodar no ESP32-S3 com ILI9341:

1. Adicione `cybersec_game.h` e `cybersec_game.c` ao componente `main/` do projeto ESP-IDF.
2. No `app_main()`, após inicializar o driver LVGL:
   ```c
   cybersec_start();
   ```
3. No handler de botões/joystick (FreeRTOS task), chame:
   ```c
   cybersec_sdl_key_event(SDLK_UP, true);    // botão pressionado
   cybersec_sdl_key_event(SDLK_UP, false);   // botão solto
   ```

> Os valores `SDLK_*` são `#define` numéricos no topo de `cybersec_game.c`.  
> No ESP-IDF, mapeie os GPIOs dos botões para esses mesmos valores.

---

## Extensões Sugeridas

- [ ] Tileset real com `lv_image` (bitmap pixel-art exportado como C array)
- [ ] Animação do personagem ao caminhar (`lv_anim` no frame do sprite)
- [ ] Som via buzzer PWM no ESP32 ao detectar ransomware (`ledc_set_freq`)
- [ ] Placar persistente em NVS (ESP32) ou arquivo local (PC)
- [ ] Terceira sala — Sala de Servidores — com eventos críticos de maior frequência
- [ ] Barra de stamina do analista (uso excessivo de NFC cansa o personagem)

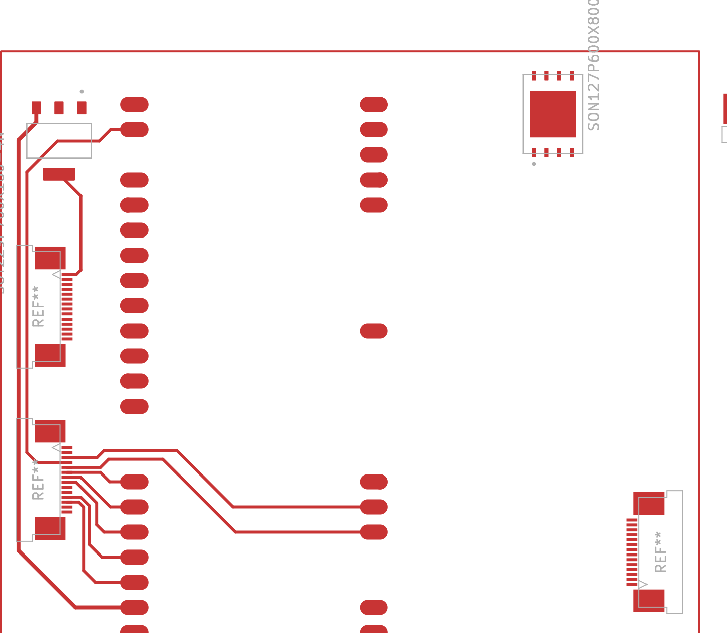
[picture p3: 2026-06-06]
hardware/pcb/PCB/_view_esp.png

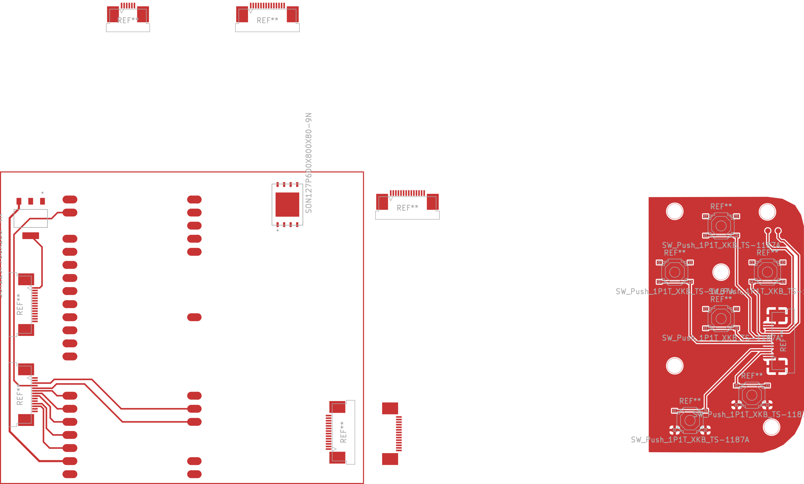
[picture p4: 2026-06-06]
hardware/pcb/PCB/_view_full.png

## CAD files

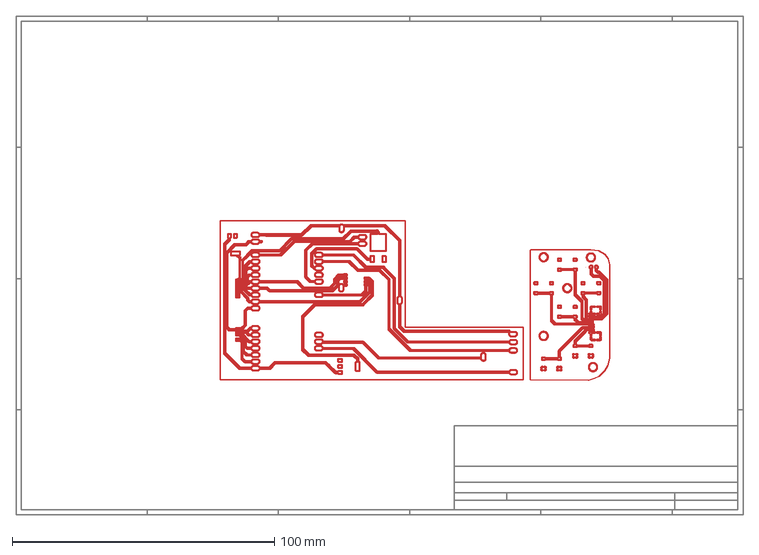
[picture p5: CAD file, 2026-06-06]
hardware/pcb/PCB/PCB.dxf
277.0 x 190.0 mm

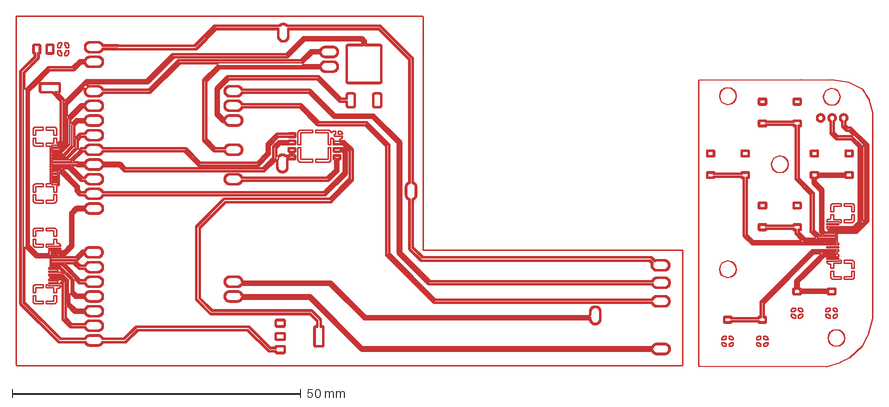
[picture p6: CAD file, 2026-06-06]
hardware/pcb/PCB/PCB-F_Cu.dxf
148.4 x 60.7 mm

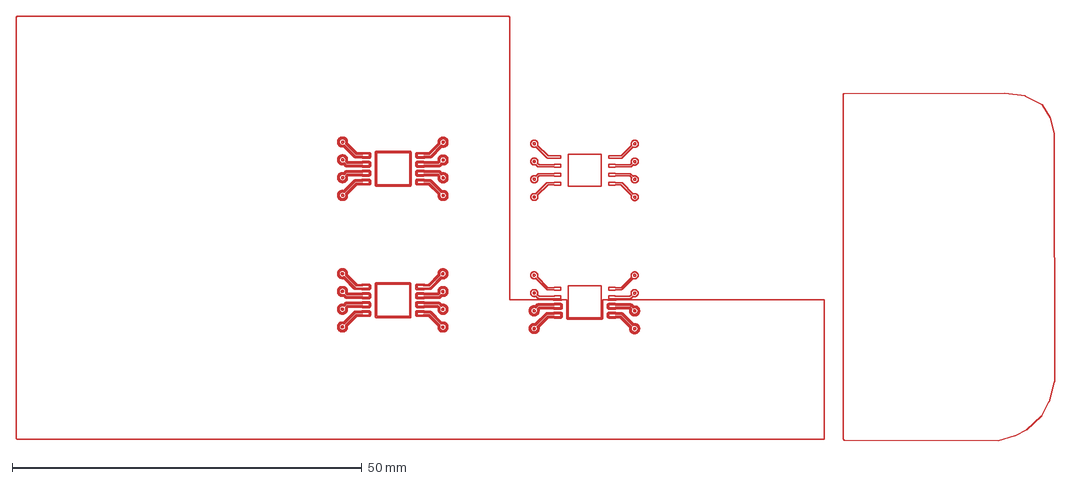
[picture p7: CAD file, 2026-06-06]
hardware/pcb/PCB/PCB.kicad_pcb_pads-F_Cu.dxf
148.4 x 60.7 mm

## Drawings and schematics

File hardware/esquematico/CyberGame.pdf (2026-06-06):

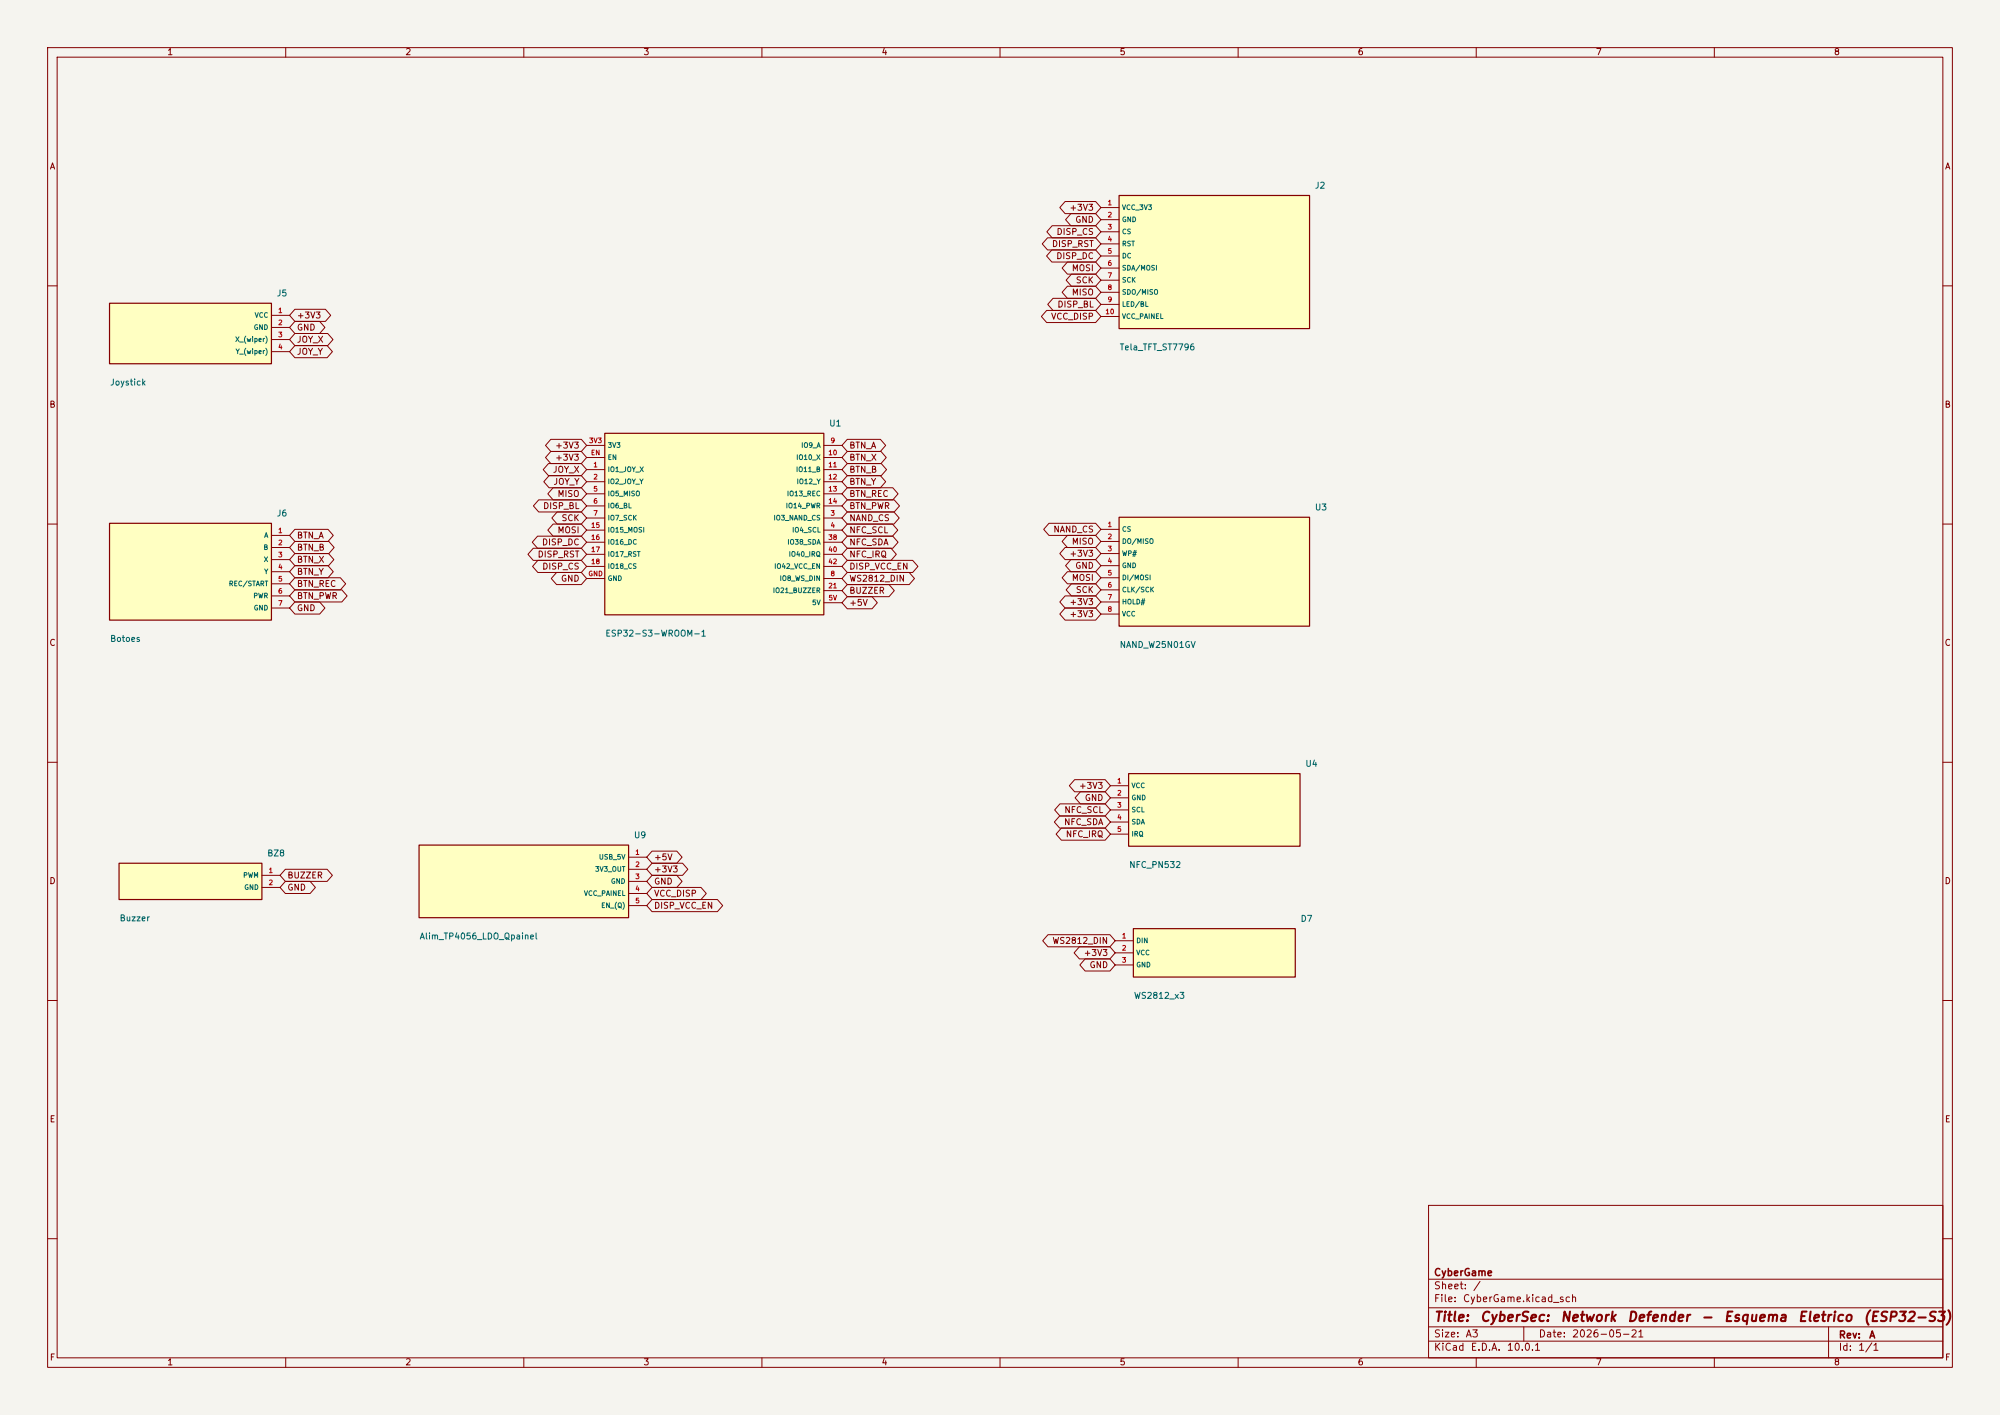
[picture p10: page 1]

CyberGame
Sheet: /
File: CyberGame.kicad_sch
Title: CyberSec: Network Defender - Esquema Eletrico (ESP32-S3)

Size: A3 | Rev: A | F Date: 2026-05-21
KiCad E.D.A. 10.0.1 | Id: 1/1

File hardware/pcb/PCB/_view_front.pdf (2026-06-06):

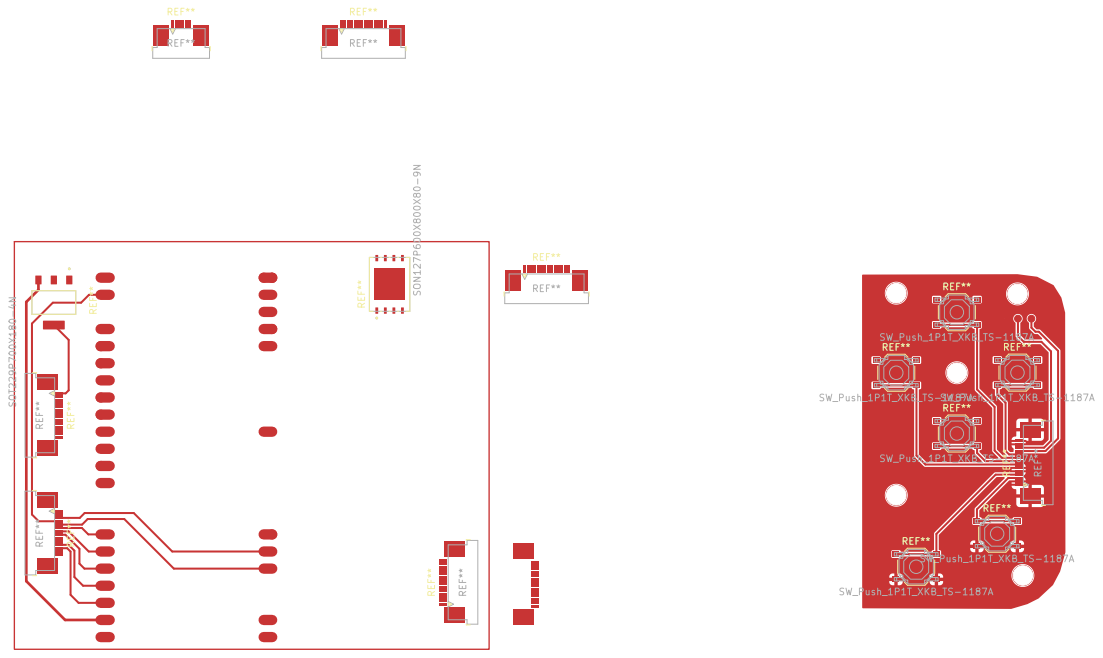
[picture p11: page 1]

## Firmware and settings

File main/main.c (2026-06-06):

#include <stdint.h>
#include <stdio.h>
#include "freertos/FreeRTOS.h"
#include "freertos/task.h"
#include "esp_idf_version.h"
#include "esp_log.h"
#include "esp_system.h"

#include "version.h"
#include "pmu.h"
#include "button_hal.h"
#include "joystick_hal.h"
#include "nfc_hal.h"
#include "display_hal.h"
#include "ws2812_hal.h"
#include "buzzer_hal.h"
#include "sd_hal.h"
#include "hal_bridge.h"
#include "ui_debug.h"     /* modo dev — acessivel pelo combo Y+START */
#include "engine.h"       /* gameplay loop */

static const char *TAG = "APP_MAIN";

/* ===== MODO DE TESTE REMOTO (mude SO este numero entre 1 e 0) ==============
 * 1 = BYPASSA o botao PWR (boota direto em NORMAL) + LIGA o jogador-fantasma
 *     (task que joga sozinha e loga tudo no console). Para testar sem o
 *     hardware fisico.
 * 0 = comportamento normal: segura PWR pra ligar, sem fantasma (producao).
 * ========================================================================== */
#define DEV_TEST_MODE   0

#define DEV_COMBO_POLL_MS   100
#define DEV_COMBO_HOLD_MS   2000

/* Combo dev: Y + START ja pressionados ao entrar em detect_dev_combo
 * e segurados continuamente por DEV_COMBO_HOLD_MS -> entra em ui_debug.
 * Caso contrario retorna imediatamente.
 *
 * Detecta assim que main.c termina os inits — o usuario pode comecar a
 * segurar o combo durante o splash anterior do PMU e ainda pegar. */
#if !DEV_TEST_MODE
static bool detect_dev_combo(void)
{
    if (button_hal_peek(BTN_Y) != BTN_PRESSED ||
        button_hal_peek(BTN_START) != BTN_PRESSED) {
        return false;
    }
    ESP_LOGI(TAG, "Combo dev Y+START detectado. Segure por %d ms para confirmar.",
             DEV_COMBO_HOLD_MS);
    for (int waited = 0; waited < DEV_COMBO_HOLD_MS; waited += DEV_COMBO_POLL_MS) {
        if (button_hal_peek(BTN_Y) != BTN_PRESSED ||
            button_hal_peek(BTN_START) != BTN_PRESSED) {
            ESP_LOGI(TAG, "Combo desfeito antes dos %d ms. Seguindo boot normal.",
                     DEV_COMBO_HOLD_MS);
            return false;
        }
        vTaskDelay(pdMS_TO_TICKS(DEV_COMBO_POLL_MS));
    }
    return true;
}
#endif /* !DEV_TEST_MODE */

static const char *reset_reason_name(esp_reset_reason_t r)
{
    switch (r) {
        case ESP_RST_POWERON:    return "POWERON";
        case ESP_RST_EXT:        return "EXT";
        case ESP_RST_SW:         return "SW";
        case ESP_RST_PANIC:      return "PANIC";
        case ESP_RST_INT_WDT:    return "INT_WDT";
        case ESP_RST_TASK_WDT:   return "TASK_WDT";
        case ESP_RST_WDT:        return "OTHER_WDT";
        case ESP_RST_DEEPSLEEP:  return "DEEPSLEEP_WAKE";
        case ESP_RST_BROWNOUT:   return "BROWNOUT";
        case ESP_RST_SDIO:       return "SDIO";
        default:                 return "UNKNOWN";
    }
}

static void log_boot_banner(void)
{
    const esp_reset_reason_t r = esp_reset_reason();
    ESP_LOGI(TAG, "======================================================");
    ESP_LOGI(TAG, "  CyberGame v" CYBERGAME_VERSION_STR " (idf %s)", IDF_VER);
    ESP_LOGI(TAG, "  reset reason: %s", reset_reason_name(r));
    ESP_LOGI(TAG, "======================================================");
}

void app_main(void)
{
    log_boot_banner();

    ESP_ERROR_CHECK(pmu_init());

#if DEV_TEST_MODE
    /* BYPASS: forca boot NORMAL sem segurar PWR (teste remoto). Pula o latch
     * e o monitor de shutdown (evita deep sleep acidental com PWR flutuando). */
    ESP_LOGW(TAG, "[DEV] DEV_TEST_MODE=1 — PMU latch BYPASSADO (boot NORMAL forcado)");
    const pmu_boot_mode_t mode = PMU_BOOT_NORMAL;
#else
    ESP_LOGI(TAG, "Avaliando Power Latch...");
    const pmu_boot_mode_t mode = pmu_check_boot_mode();

    if (mode == PMU_BOOT_ABORT) {
        ESP_LOGW(TAG, "Botao solto prematuramente. Voltando ao Deep Sleep.");
        pmu_enter_deep_sleep();
    }

    /* Monitor de PWR para shutdown (hold longo -> deep sleep). */
    xTaskCreate(pmu_shutdown_monitor_task, "pmu_monitor", 3072, NULL, 5, NULL);
#endif

    /* PMU_BOOT_NORMAL daqui em diante. */
    ESP_LOGI(TAG, "Boot NORMAL confirmado! Iniciando sistema...");

    /* ============================================================
     * === MODO BRING-UP TEMPORARIO (2026-05-26) — INICIO ===
     * Todos os HALs de hardware aqui tolerantes a falha: log + segue.
     * Para reverter: ver CyberGameCore/CHANGELOG/entries/2026-05-26T1945-bring-up-mode-completo.md
     * Bloco original preservado integralmente nessa entrada.
     * ============================================================ */

    if (button_hal_init() != ESP_OK) {
        ESP_LOGW(TAG, "[BRING-UP] buttons ausentes — boot continua sem input de botoes.");
    }
    if (joystick_hal_init() != ESP_OK) {
        ESP_LOGW(TAG, "[BRING-UP] joystick ausente — boot continua sem ADC do analog.");
    }
    if (nfc_hal_init() != ESP_OK) {
        ESP_LOGW(TAG, "[BRING-UP] NFC ausente — boot continua sem leitura de cartao.");
    }
    if (ws2812_hal_init() != ESP_OK) {
        ESP_LOGW(TAG, "[BRING-UP] WS2812 ausente — boot continua sem LEDs de feedback.");
    } else {
        /* Diagnostico de hardware: 3 LEDs em vermelho por 300 ms.
         * Se nao acender visivelmente, o driver iniciou mas a eletrica
         * (alimentacao/GND/GPIO 8/data line) tem problema. Remover apos
         * confirmar que a tira responde. */
        ws2812_hal_set_all(80, 0, 0);
        ws2812_hal_refresh();
        vTaskDelay(pdMS_TO_TICKS(300));
        ws2812_hal_clear();
        ws2812_hal_refresh();
    }
    if (buzzer_hal_init() != ESP_OK) {
        ESP_LOGW(TAG, "[BRING-UP] buzzer ausente — boot continua sem SFX.");
    }

    /* Display: sem ele nao tem como rodar LVGL/engine/ui_debug. Marca flag. */
    bool ui_ok = true;
    if (display_hal_init() != ESP_OK) {
        ESP_LOGW(TAG, "[BRING-UP] display ausente — boot continua mas sem video.");
        ui_ok = false;
    } else if (hal_bridge_init() != ESP_OK) {
        ESP_LOGW(TAG, "[BRING-UP] hal_bridge falhou — boot continua mas sem UI.");
        ui_ok = false;
    } else {
        display_hal_set_backlight_percent(70);
    }

    /* microSD (slot do modulo de display). O barramento SPI2 ja foi inicializado
     * pelo display acima. Fase 1: so detectar/montar e listar a raiz. Tolerante:
     * se falhar, boot segue (as telas ficam sem assets ate a migracao Fase 2). */
    if (sd_hal_init() != ESP_OK) {
        ESP_LOGW(TAG, "[BRING-UP] microSD ausente — boot continua sem storage.");
    } else {
        sd_hal_list_root();
        sd_hal_selftest();   /* valida escrita+leitura do cartao */
    }

    /* Sem UI nao tem como rodar engine nem ui_debug (ambos chamam LVGL).
     * Idle com heartbeat de 5s pra deixar UART respirar e mostrar que vive. */
    if (!ui_ok) {
        ESP_LOGW(TAG, "[BRING-UP] UI indisponivel — pulando engine/ui_debug. Heartbeat a cada 5s.");
        while (1) {
            ESP_LOGW(TAG, "[BRING-UP] alive — sem UI");
            vTaskDelay(pdMS_TO_TICKS(5000));
        }
    }

#if !DEV_TEST_MODE
    /* Combo dev: Y+START segurados juntos por 2s -> ui_debug.
     * Caso contrario, inicia o engine normalmente. (Pulado em DEV_TEST_MODE
     * pra nao depender de leitura de botao com a placa sem interacao.) */
    if (detect_dev_combo()) {
        ESP_LOGW(TAG, "MODO DEV: iniciando ui_debug ao inves do engine.");
        if (ui_debug_init() != ESP_OK) {
            ESP_LOGE(TAG, "ui_debug_init falhou — boot continua em idle.");
        }
        while (1) vTaskDelay(pdMS_TO_TICKS(1000));
    }
#endif

    /* MODO GAME normal. */
    if (engine_init() != ESP_OK) {
        ESP_LOGE(TAG, "engine_init falhou — boot continua em idle.");
        while (1) vTaskDelay(pdMS_TO_TICKS(1000));
    }
    engine_set_test_mode(DEV_TEST_MODE);   /* liga o jogador-fantasma se ==1 */
    if (engine_start() != ESP_OK) {
        ESP_LOGE(TAG, "engine_start falhou — engine nao recebera eventos.");
    }
    /* === MODO BRING-UP TEMPORARIO (2026-05-26) — FIM === */

    while (1) {
        vTaskDelay(pdMS_TO_TICKS(1000));
    }
}

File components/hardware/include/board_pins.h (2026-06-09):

#pragma once

#include "driver/gpio.h"

#ifdef __cplusplus
extern "C" {
#endif

/* === CyberGame board pin map ====================================================
 *
 * Mapa unico de GPIOs do console portatil ESP32-S3, agrupado por subsistema
 * fisico. Esta e a unica fonte de verdade: HALs em components/hardware/
 * importam destes defines, nunca declaram pinos proprios.
 *
 * Agrupamento atual reflete o layout do protoboard (PCB ainda nao fechada):
 *   - ADC1 (joystick) ............ GPIO  1, 2     (ADC1_CH0, ADC1_CH1)
 *   - Botoes frontais ............ GPIO  9..13    (sequenciais)
 *   - PMU (power button) ......... GPIO 14
 *   - NFC PN532 (I2C) ............ GPIO  4, 39, 40
 *   - Display ST7796 (SPI2) ...... GPIO  5, 6, 7, 15, 16, 17, 42
 *   - microSD (SPI2, slot do modulo) GPIO 15, 16, 18, 47
 *
 * Se mudar pinout, edite SO este arquivo. Atencao aos pinos compartilhados
 * (DISP/SD via SPI2): mude os dois lados juntos.
 * ============================================================================ */

/* --- Joystick analogico (ADC1 oneshot) -------------------------------------- */
#define BOARD_PIN_JOY_X_ADC          GPIO_NUM_1   /* ADC1_CH0 */
#define BOARD_PIN_JOY_Y_ADC          GPIO_NUM_2   /* ADC1_CH1 */

/* --- Botoes frontais -------------------------------------------------------- */
#define BOARD_PIN_BTN_A              GPIO_NUM_9
#define BOARD_PIN_BTN_X              GPIO_NUM_10
#define BOARD_PIN_BTN_B              GPIO_NUM_11
#define BOARD_PIN_BTN_Y              GPIO_NUM_12
#define BOARD_PIN_BTN_START          GPIO_NUM_13

/* --- PMU (Power Management Unit) -------------------------------------------- */
#define BOARD_PIN_PMU_PWR            GPIO_NUM_14  /* power button + EXT0 wakeup */

/* --- NFC PN532 (I2C) -------------------------------------------------------- */
#define BOARD_PIN_NFC_SCL            GPIO_NUM_4
#define BOARD_PIN_NFC_SDA            GPIO_NUM_39
#define BOARD_PIN_NFC_IRQ            GPIO_NUM_40

/* --- Display ST7796 (SPI2_HOST) --------------------------------------------- */
#define BOARD_PIN_DISP_CS            GPIO_NUM_5
#define BOARD_PIN_DISP_RST           GPIO_NUM_6
#define BOARD_PIN_DISP_DC            GPIO_NUM_7
#define BOARD_PIN_DISP_MOSI          GPIO_NUM_15  /* compartilhado com microSD */
#define BOARD_PIN_DISP_SCK           GPIO_NUM_16  /* compartilhado com microSD */
#define BOARD_PIN_DISP_BL            GPIO_NUM_17  /* backlight via LEDC PWM */
#define BOARD_PIN_DISP_PWR_EN        GPIO_NUM_42  /* PNP BC327 driver: 0=liga VCC, 1=corta */

/* --- Feedback ao jogador (LED enderecavel + buzzer) ------------------------- */
#define BOARD_PIN_WS2812_DATA        GPIO_NUM_8   /* 3 LEDs WS2812 via RMT */
#define BOARD_PIN_BUZZER             GPIO_NUM_21  /* piezo passivo via LEDC PWM */

/* --- Cartao microSD (slot embutido no modulo de display, SPI2_HOST) ---------
 * Compartilha MOSI/SCK/MISO com o display no mesmo barramento SPI2_HOST.
 * Pinos do modulo LCDWIKI: 9 SDO(MISO)->GPIO18, 14 SD_CS->GPIO47. */
#define BOARD_PIN_SD_MOSI            GPIO_NUM_15  /* === DISP_MOSI */
#define BOARD_PIN_SD_SCK             GPIO_NUM_16  /* === DISP_SCK */
#define BOARD_PIN_SD_MISO            GPIO_NUM_18  /* compartilhado no SPI2_HOST */
#define BOARD_PIN_SD_CS              GPIO_NUM_47

#ifdef __cplusplus
}
#endif

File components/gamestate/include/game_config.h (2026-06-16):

#pragma once

/*
 * game_config.h — Constantes derivadas da calibração.
 * Não edite aqui: use calibracao.h para ajustar os valores do jogo.
 */

#include "calibracao.h"

/* ── Duração do expediente ──────────────────────────────────────────────────
 * CAL_VELOCIDADE_TEMPO 0→5min  50→3min  100→50s  */
#ifdef CYBERSIM
  #define EXPEDIENTE_DURACAO_MS     (5 * 60 * 1000)
#else
  #define EXPEDIENTE_DURACAO_MS     (300000 - (uint32_t)(CAL_VELOCIDADE_TEMPO) * 2500u)
#endif

#define HORA_INICIO_JOGO_MIN        (8  * 60)
#define HORA_FIM_JOGO_MIN           (18 * 60)

/* ── Vidas ──────────────────────────────────────────────────────────────────*/
#define VIDAS_INICIAIS              CAL_VIDAS_INICIAIS

/* ── Sequência de tarefas (flow scripted) ──────────────────────────────────
 * As tarefas aparecem numa ordem fixa. srv_primeiro e srv_segundo são
 * sorteados no reset e determinam qual servidor recebe cada evento.
 *
 * VERDE_SPAWN_MS       — verde aparece X ms após o expediente iniciar (tempo real).
 * AMARELA_TOLERANCIA_MS — se a amarela não for concluída em X ms, vira risco.
 * RANSOM_END_BEFORE_MS  — ransomware deve TERMINAR X ms antes do fim.
 * TAREFA_SPAWN_GAP_MS   — gap mínimo entre spawns consecutivos da sequência.
 *
 * Obs: CAL_TAREFA_VERDE_INICIO / CAL_TAREFA_AMARELA_INICIO / CAL_TAREFA_VERMELHO_INICIO
 * de calibracao.h não controlam mais os tempos de spawn (sequência agora é fixa). */
#define VERDE_SPAWN_MS              5000u
#define AMARELA_TOLERANCIA_MS       40000u
#define RANSOM_END_BEFORE_MS        20000u
#ifdef CYBERSIM
  #define TAREFA_SPAWN_GAP_MS       (20 * 1000)
#else
  #define TAREFA_SPAWN_GAP_MS       (10 * 1000u)
#endif

/* ── Ataques vermelhos ──────────────────────────────────────────────────────
 * CAL_DIFICULDADE_ATAQUES 0=fácil  50=padrão  100=brutal
 * Sem respawn automático: cada ataque spawna uma vez por run via gates do gamestate. */
#ifdef CYBERSIM
  #define VERMELHO_TIMER_MS             (60 * 1000)
#else
  /* Tempo para mitigar: 0→40s  50→22s  100→5s */
  #define VERMELHO_TIMER_MS             ((uint32_t)(5 + (100 - CAL_DIFICULDADE_ATAQUES) * 35 / 100) * 1000u)
#endif

#define VERMELHO_AGRAVADO_MULT_PCT      50
#define NFC_LEITURA_COOLDOWN_MS         1000u
#define EVENTO_COOLDOWN_GLOBAL_MS       (5 * 1000u)

/* ── Pontuação ──────────────────────────────────────────────────────────────*/
#define SCORE_VERDE                     10
#define SCORE_AMARELA                   20
#define SCORE_VERMELHO_BASE             50
#define SCORE_VELOCIDADE_MAX            50

/* ── NFC / Deploy ───────────────────────────────────────────────────────────*/
#define ACTION_LOCK_MS                  1500u
#define SYSTEM_DEPLOY_MS                4000u

/* ── UI ─────────────────────────────────────────────────────────────────────*/
#define TIMEOUT_TELA_FINAL_MS           (30 * 1000u)
#define MENU_NAV_DEBOUNCE_MS            300u

/* ── Ticks ──────────────────────────────────────────────────────────────────*/
#define ENGINE_TICK_PERIOD_MS           100u

/* ── Jogador ────────────────────────────────────────────────────────────────
 * Sprite fixo 32×48 (4 linhas × 3 frames). Não altere W/H aqui.          */
#define PLAYER_FRAME_W                  32
#define PLAYER_FRAME_H                  48

/* Velocidade de movimento: CAL_VELOCIDADE_JOGADOR 0→max=1  50→max=3  100→max=6 */
#define PLAYER_STEP_MIN_PX              (1u + (unsigned)(CAL_VELOCIDADE_JOGADOR) / 67u)
#define PLAYER_STEP_MAX_PX              (1u + (unsigned)(CAL_VELOCIDADE_JOGADOR) * 5u / 100u)

/* Deadzone do joystick: CAL_ZONA_MORTA_JOYSTICK 0→0  50→30  100→60 */
#define JOYSTICK_DEFLEXAO_MIN           50u
#define PLAYER_JOY_DEADZONE             ((unsigned)(CAL_ZONA_MORTA_JOYSTICK) * 60u / 100u)

/* Boost eixo X: CAL_BOOST_EIXO_X 0→×1,0  50→×1,5  100→×2,0 */
#define JOY_X_BOOST_PCT                 (100u + (unsigned)(CAL_BOOST_EIXO_X))

/* Animação walk: CAL_VELOCIDADE_ANIMACAO 0→200ms  50→125ms  100→50ms */
#define PLAYER_WALK_PERIOD_MS           (200u - (unsigned)(CAL_VELOCIDADE_ANIMACAO) * 150u / 100u)

#define SPAWN_DOOR_MARGIN_PX            16u

/* ── Diálogo (typewriter) ───────────────────────────────────────────────────*/
#define DIALOG_TYPE_PERIOD_MS           30u

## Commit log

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2026-05-04 fix: correção de erro para voltar a recepcao
2026-05-07 fix: correção de etxto superior e posição da sec
2026-05-07 fix: correção de erro na task 2
2026-05-09 feat: adiciona HAL do NFC PN532 via I2C com IRQ + start/stop scanning
    - Protocolo PN532 minimo (frame builder, ACK, response parser) sobre i2c_master.
    - IRQ-driven (GPIO 16): ISR libera semaforo, task acorda imediatamente.
    - API start/stop scanning: caller (game logic) controla quando varrer.
    - RFConfiguration MxRtyPassiveActivation=1 best-effort para detection rapida.
    - De-dup de UID: mesmo cartao segurado = 1 evento, sair e voltar = evento novo.
    - hal_common: install ISR service uma unica vez, evitando "already installed".
    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
2026-05-09 feat: storage_hal Camada 1 — read/write/erase de pagina + bad block check + POST destrutivo
2026-05-09 feat: storage_hal suite de validacao fisica (registers + multi-region + bad block scan)
2026-05-09 feat: B1 — recovery mode com USB CDC (TinyUSB) + script PING/PONG no PC
2026-05-11 feat: display_hal (ST7796 SPI) + hal_bridge LVGL + ui_debug
    - display_hal: power_on via NPN GPIO 42, LEDC backlight, SPI2 40MHz,
    esp_lcd_st7796 + mirror/swap_xy + invert_color=false
    - hal_bridge: LVGL 9.3 com strip 32 linhas double-buffered DMA,
    swap G<->B inplace (PCB tem fios trocados), tick timer 5ms
    - ui_debug: tela live com botoes A/B/X/Y, joystick X/Y + crosshair,
    NFC scan state + UID, uptime + heap DRAM/PSRAM. Updates diff-gated
    (cache do estado desenhado + deadzone visual no joystick) para nao
    saturar o LVGL e disparar task_wdt no CPU 0
    - sdkconfig.defaults: PSRAM Octal 80MHz, Flash 16MB, LVGL RGB565,
    FreeRTOS lock, LV_DRAW_BUF_STRIDE_ALIGN=1 (corrige letras alienigenas)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
    [display_hal.c, hal_bridge.c, main.c]
2026-05-11 fix(ui_debug): refresh via lv_timer no lugar de task FreeRTOS
    A task FreeRTOS dedicada para refresh (com lv_lock/unlock + vTaskDelay)
    criava janela de concorrencia com a task lvgl do hal_bridge — ambas
    disputando o mesmo lv_lock disparava task_wdt no CPU compartilhado
    mesmo com diff-gating completo nos widgets.
    Migrado para lv_timer_create: o callback ui_refresh_cb roda dentro do
    proprio lv_timer_handler, sem precisar de lock externo e sem competir
    com o render. Padrao recomendado pelo LVGL.
    Tambem removidos ESP_LOGI de diagnostico que ficaram dentro do escopo
    do lv_lock — UART sincrona (~7ms/linha) bloqueando o lock era parte
    do problema.
2026-05-11 feat(asset_store): camada de arquivos sobre storage_hal (Etapa 1)
    API read-only para acessar assets do jogo guardados na NAND
    W25N01GV via storage_hal. Layout fixo por categoria:
    Bloco 1-3 manifest (3 copias rotativas)
    Bloco 4-99 SPRITES (96 blocos = 12 MB)
    Bloco 100-149 FONTES (50 blocos = 6.25 MB)
    Bloco 150-199 SONS (50 blocos = 6.25 MB)
    Manifest cabe em 1 pagina (header 64 B + 31 entries de 64 B).
    Robustez: 3 copias rotativas pick max generation, CRC32 do header
    e por entry, validacao do bad block marker antes de ler.
    API: asset_store_init/get_info/read/count/list. Write API e
    integracao no recovery vem nas Etapas 2 e 3.
    Em fresh boot sem asset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
    [asset_store.c, main.c]
2026-05-13 feat(button_hal): adiciona BTN_START no GPIO 3 dual-use com REC
    - enum ganha BTN_START antes de BTN_MAX_COUNT
    - gpio_config inclui GPIO 3 com mesma config dos outros 4
    - settle 100ms + espera HIGH no GPIO 3 antes da ISR (evita evento espurio
    se usuario ainda segura REC pos-boot)
    - main.c: names[] na button_logger_task ganha "START"
    PMU usa GPIO_INTR_DISABLE no GPIO 3, so polling em pmu_check_boot_mode;
    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
2026-05-13 feat: esqueleto de engine + fsm + ui com menu basico
    Cria 3 componentes vazios pre-existentes:
    - components/fsm/ maquina de estados central (states + events stubs)
    - components/engine/ task GameEngine (Core 0) consumindo input_queue +
    tick periodico; nfc_config.h com 3 UIDs placeholder;
    game_config.h com defaults da matriz-reacao-ataques
    - components/ui/ router de telas (splash, menu, placeholder, pause)
    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
2026-05-13 refactor(main): substitui ui_debug por engine, mantem modo dev via combo
    - Remove 4 logger tasks de teste (button_logger, joystick_logger,
    nfc_logger, nfc_test_trigger) — funcoes equivalentes agora ficam
    no engine/fsm.
    - Substitui ui_debug_init() pelo engine_init() + engine_start() no
    fluxo de boot normal.
    - ui_debug fica acessivel via combo dev: Y+START segurados juntos por
    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
2026-05-13 fix(engine): linka ui diretamente em vez de via weak symbol
    A declaracao 'extern weak ui_init' fazia o linker omitir o componente ui
    quando ele estava so como PRIV_REQUIRES, deixando o ponteiro NULL no
    runtime ('ui_init nao linkado — modo headless') e a tela em branco apos
    o boot normal.
    - engine.c: inclui ui.h e chama ui_init/ui_show_splash direto (forca o
    linker a puxar o componente ui).
    - engine.c: ui_init falhando agora aborta engine_init em vez de seguir
    sem tela.
    - fsm.c: temporariamente sobe nivel de log de BUTTON/NFC para INFO
    durante validacao da Etapa A. TODO marcado para baixar a DEBUG
    quando a Etapa C estabilizar.
    Reportado durante validacao da Etapa A pelo usuario.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
    [engine.c]
2026-05-13 fix(display): pipeline de cores via byte swap + BGR + R boost
    Calibracao empirica em 24 cores com Samsung S24 como referencia sRGB
    identificou 3 problemas acumulados no pipeline LVGL -> ST7796:
    1. ESP32 little-endian vs ST7796 big-endian no SPI -> byte swap necessario
    em cada uint16_t antes do flush. Antes era swap_gb_inplace presumindo
    G/B trocados na PCB (hipotese desmentida).
    2. Display espera BGR no controlador, nao RGB. Setado
    LCD_RGB_ELEMENT_ORDER_BGR em panel_cfg.
    3. LEDs vermelhos do painel tem luminancia atenuada (~3x menor que G/B).
    Boost 2x no canal R com clamp em 5 bits antes do byte swap.
    Funcao swap_gb_inplace renomeada para rb_boost_and_byte_swap_inplace,
    fazen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
    [display_hal.c, hal_bridge.c]
2026-05-13 feat(fsm): sub-FSM de gameplay com 5 sub-estados (Etapa C bloco 1)
    Adiciona sub-estados internos a GAME_STATE_GAMEPLAY:
    EXPLORANDO -> TERMINAL_ABERTO -> WAITING_CARD -> ACTION_LOCK
    -> SYSTEM_DEPLOY -> volta. Gatilhos provisorios via botoes
    fisicos enquanto NFC real e timeline nao chegam.
    - fsm_gameplay.h: enum + getter + nome
    - fsm.c: gameplay_handle_event com transicoes por botao +
    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
2026-05-14 feat(assets): pipeline de geracao + componente assets + asset_store etapa 2
    Pipeline tools/:
    - convert_assets.py: PNG -> array C lv_image_dsc_t (RGB565/RGB565A8)
    com crop ao bbox + magic header + stride correto (w*2)
    - extract_collisions.py: PAREDES_E_OBJETOS_02.png -> tabela retangulos
    tile-based 16px com merge horizontal+vertical; *_NULL.png ->
    gatilhos tipados por cor (NPC, porta, tarefa, spawn)
    Componente components/assets:
    - include/assets.h API publica unica (re-exporta images + meta)
    - include/assets_images.h declaracoes extern (gerado)
    - include/assets_meta.h offsets cropados por imagem (gerado)
    - include/collision_data.h enum + struct retangulos (gerado)
    - generated/img_recep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
    [partitions.csv]
2026-05-14 feat(c2): Recepcao + Empresa com player, colisao, dialogo e fluxo entre salas
    FSM:
    - gameplay_sala_t (RECEPCAO/EMPRESA) com getter/setter
    - entrada em GAMEPLAY reseta sala pra RECEPCAO so se veio de MENU/SPLASH
    Engine:
    - engine_task observa mudanca de sala e chama ui_show_recepcao/empresa
    UI router: 2 telas novas (UI_SCREEN_RECEPCAO, UI_SCREEN_EMPRESA);
    placeholder vira legacy; assets em REQUIRES
    screen_recepcao.c:
    - 6 camadas LVGL (piso/paredes/player/complemento/npc/icone)
    - player 32x48 do sheet via lv_image_set_offset; joystick + walk 8fps
    - colisao AABB com raspar parede (eixos separados)
    - gatilhos: area marrom -> NPC vira de frente + dialogo auto-inicia;
    area vermelha -> troca pr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
    [engine.c]
2026-05-14 feat(c2): ajustes de gameplay pos-teste HW + correcoes (versao beta)
    Movimento:
    - joystick X e Y invertidos (joystick_hal entrega ambos com sinal
    trocado em relacao a tela): jx>0=direita, jy>0=baixo
    - velocidade proporcional a deflexao reduzida 20% (PSTEP 2-6)
    - ordem das linhas do sprite confirmada: DOWN/LEFT/RIGHT/UP
    Interacao:
    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
2026-05-14 docs(hardware): esquema eletrico + correcao do comentario NPN do display
    - hardware/ESQUEMA_ELETRICO.md: referencia completa pra montar o schematic (pinout, barramentos SPI/I2C, energia, checklist)
    - display_hal.c: comentario do GPIO 42 corrigido de PNP para NPN (1=liga VCC)
    [display_hal.c]
2026-05-14 feat(tools): uploader de assets via USB CDC (camada de transporte)
    - recovery_protocol.py: modulo compartilhado — framing, CRC32 e a classe RecoveryClient com os 10 comandos do protocolo
    - asset_uploader.py: CLI com ping/ls/download/erase/reset/selftest
    - test_ping.py refatorado para reusar o modulo compartilhado
    - validado em HW: ping, ls (cold start), selftest
2026-05-14 feat(assets): codec PNG->blob + registry + upload pra NAND (Fase 4b)
    - asset_blob.h: contrato do header de blob (32 B: magic, w/h, stride, offsets de crop, pixel_format, data_size)
    - asset_codec.py: encoder PNG -> RGB565/RGB565A8 compartilhado
    - asset_registry.json: 17 assets renderizaveis (type/id/name estaveis)
    - convert_assets.py refatorado pra usar o codec (output byte-identico, git diff vazio)
    - asset_uploader.py: comandos upload e download --png
    - validado em HW: 17 assets gravados (2.17 MB), ls + download --png round-trip OK
2026-05-15 fix(ui): inverte eixo Y do joystick nas 3 telas (jogo + menu)
    O eixo Y chegava com o sentido cima/baixo trocado. Padronizado nas 3 telas que usam joystick (recepcao, empresa, menu): j.y>0 = baixo. O eixo X segue invertido na origem (jx = -j.x) — nao foi reportado problema nele.
2026-05-15 fix(build): corrige simbolo CONFIG_LV_OS_FREERTOS — lv_lock era no-op
    sdkconfig.defaults usava CONFIG_LV_USE_OS_FREERTOS, simbolo que nao existe no Kconfig do LVGL (o correto e CONFIG_LV_OS_FREERTOS, choice LV_USE_OS). Era silenciosamente ignorado -> LV_OS_NONE -> lv_lock()/lv_unlock() viravam no-op inline.
    Consequencia: engine_task e a task lvgl NAO eram serializados, apesar de ambos chamarem lv_lock(). screen_*_destroy (lv_obj_delete) rodava concorrente com lv_timer_handler -> use-after-free -> Guru Meditation em lv_event_mark_deleted ao trocar de sala/tela.
    Corrigido em sdkconfig.defaults (fonte versionada) e no sdkconfig gerado.
2026-05-15 feat(ui): migra screen_recepcao para asset_loader (NAND) — Fase 6 (1/2)
    - screen_recepcao carrega seus 9 assets da NAND pra PSRAM no build (load_all_assets) e libera no destroy (free_all_assets, apos lv_obj_delete)
    - usa s_assets[].dsc / .off_x / .dsc.header.w no lugar dos arrays C embarcados img_rec_* e dos IMG_REC_*_META
    - linker faz GC dos arrays de img_recepcao.c sozinho (~920 KB de flash a menos)
    - validado em HW: recepcao renderiza da NAND, 12+ trocas de tela sem crash
    - screen_empresa ainda usa arrays embarcados (migra na parte 2)
2026-05-15 perf(assets): cache load-once no asset_loader
    Cada asset e lido da NAND uma unica vez e mantido residente na PSRAM pelo resto da sessao. asset_loader_load checa o cache antes de ler; asset_loader_free vira no-op para assets cacheados (_buf == NU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
    Elimina o relê de ~1 MB da NAND a cada entrada de tela. Validado em HW: 1a entrada na recepcao ~770ms, 2a entrada ~30ms.
2026-05-15 feat(ui): migra screen_empresa para asset_loader (NAND) — Fase 6 (2/2)
    Mesmo padrao da recepcao: load_all_assets no build, free_all_assets no destroy, s_assets[].dsc no lugar dos arrays C img_emp_*/img_player e dos IMG_EMP_*_META. As poses do NPC TI (set_npc_pose) tambe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
    Com as 2 telas migradas, nenhum .c referencia mais os arrays embarcados — generated/img_*.c ficou orfao (proximo: cleanup).
2026-05-15 chore(assets): remove arrays C embarcados e smoke-test — Fase 6 cleanup
    - remove generated/img_*.c (recepcao/empresa/player) e os headers orfaos assets.h / assets_images.h / assets_meta.h — nada mais os referencia apos as 2 telas migrarem pro asset_loader
    - remove o smoke-test temporario do main.c e os includes asset_loader.h/asset_ids.h que so ele usava
    - os assets agora vivem 100%% na NAND
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2026-05-20 refactor(game-logic): elevar UI/assets ao nível pré-profissional (Fases 1-4)
    Fase 1 — Bombas-relógio:
    - game_config.h movido de engine/ para gamestate/ (folha do grafo); fsm.c e
    gamestate.c apagam defines duplicados e incluem o header
    - s_porta_armed eliminado; spawn nasce com SPAWN_DOOR_MARGIN_PX de
    afastamento da porta (cobre drift do joystick)
    - fsm_set_gameplay_sala() agora zera player_at_equipment automaticamente;
    recepção deixa de chamar set(false) defensivo a cada tick
    - Diálogo: char buf[256] + memcpy trocado por lv_label_set_text_fmt('%.*s')
    — fim do truncamento silencioso
    Fase 2 — Motor de sala compartilhado:
    - Novo screen_room.{c,h} concentra rects_overlap, ro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
    [asset_store.c, display_hal.c]
2026-05-27 refactor(hardware): centraliza GPIOs em board_pins.h com static asserts
    Cria components/hardware/include/board_pins.h como fonte unica de verdade
    para o pinout, agrupado por subsistema fisico (joystick, botoes, PMU,
    NFC, display, NAND). Cada *_hal.c importa de la em vez de declarar pinos
    locais.
    _Static_assert garante invariantes de hardware em compile-time:
    - BTN_START == PMU_REC (dual-use boot vs runtime)
    - NAND/Display compartilhando MOSI+SCK no SPI2_HOST
    - canais ADC do joystick batem com GPIOs esperados no ESP32-S3
    pmu.h removeu defines PMU_PIN_* do header publico: pinos sao detalhe de
    implementacao, nao parte do contrato. Comentario em button_hal.h
    corrigido (GPIO 3 -> 13).
    Au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
    [board_pins.h, button_hal.c, display_hal.c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]
2026-05-27 feat(hardware): asserts nos pontos de entrada publicos dos HALs (G6)
    Adiciona Design-by-Contract via assert() nas APIs publicas dos HALs
    para apanhar bugs de chamador em dev, sem custo em release (NDEBUG).
    display_hal_draw_bitmap coords sanas (x_end>x_start, dentro do
    framebuffer) + pixel_data nao-NULL
    display_hal_set_backlight_percent pct <= 100 (mantem clamp em release)
    button_hal_get_event event nao-NULL (queue NULL continua sendo
    ESP_ERR runtime)
    button_hal_peek id < BTN_MAX_COUNT (removido o mask silencioso)
    nfc_hal_wait_card card nao-NULL
    storage_hal_read_jedec_id manuf+device nao-NULL (movid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
    [button_hal.c, display_hal.c, nfc_hal.c]
2026-05-27 feat(engine): subscreve engine_task ao Task Watchdog (G8)
    Engine_task agora chama esp_task_wdt_add(NULL) no inicio e
    esp_task_wdt_reset() a cada iteracao do loop. Se algum handler da FSM
    travar (>5s sem reset), o Task WDT panica e deixa rastro no log antes
    do reset do core.
    ENGINE_TICK_PERIOD_MS=100 vs CONFIG_ESP_TASK_WDT_TIMEOUT_S=5 da folga
    de 50x — quem dispara WDT eh genuinamente loop travado, nao ruido.
    sdkconfig ja tinha:
    CONFIG_ESP_TASK_WDT_EN=y
    CONFIG_ESP_TASK_WDT_INIT=y (idle tasks dos 2 cores ja monitoradas)
    CONFIG_ESP_TASK_WDT_TIMEOUT_S=5
    CONFIG_BROWNOUT_DET=y, level 7 (max)
    CONFIG_ESP_INT_WDT=y, 300ms
    CMakeLists do engine: adiciona esp_system em PRIV_REQUIRES (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
    [engine.c]
2026-05-27 feat(main): banner de boot com versao + IDF + reset reason (G9)
    Cria main/version.h com semver simples (MAJOR/MINOR/PATCH/STR) e adiciona
    banner ASCII logo no inicio de app_main que loga:
    CyberGame v0.1.0 (idf v6.0)
    reset reason: POWERON | EXT | SW | PANIC | INT_WDT | TASK_WDT |
    OTHER_WDT | DEEPSLEEP_WAKE | BROWNOUT | SDIO | UNKNOWN
    reset reason vem de esp_reset_reason() mapeada via funcao local
    reset_reason_name() — IDF nao expoe equivalente built-in (esp_reset_reason_get_name
    nao existe).
    Em campo, esses 3 dados (versao do firmware + versao do IDF + motivo do
    ultimo reset) sao o que mais ajuda a triar falha "do nada". Especial
    utilidade pra correlacionar com o WDT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
    [main.c]
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2026-05-27 feat(entity): componente novo entity (pool + movement + y_sort)
    Implementa os 3 pilares do sistema top-down 2D descritos em
    docs/regras/07/08:
    components/entity/include/entity.h
    - struct entity_t (32 bytes): id, type, flags, x/y, sprite_w/h,
    lv_obj*, collision box (offset+w+h), sort_offset_y
    - enum entity_type_t: PLAYER, NPC, FURNITURE, PROP, TRIGGER
    - 7 flags bitmask: SOLID, MOVABLE, CARRYABLE, INTERACTABLE,
    TRIGGER, VISIBLE, YSORTED
    - helpers inline puros: entity_sort_y, entity_get_collision_rect,
    entity_apply_lv_pos
    components/entity/include/entity_pool.h + .c
    - pool estatico 64 entries (~2 KB BSS) — zero heap em runtime
    - init/clear/alloc/free/count/at idempot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
2026-05-27 feat(entity): debug_overlay para visualizar collision/pivot/sort_y
    Quando habilitado, desenha sobre todo o gameplay:
    - retangulo VERDE outline = sprite_w x sprite_h
    - retangulo VERMELHO 30% opa = collision_box (FLAG_SOLID)
    - retangulo LARANJA 30% opa = collision_box (FLAG_TRIGGER)
    - quadrado AMARELO 3x3 = pivot (x, y)
    - segmento AZUL horizontal = sort_y (apenas YSORTED)
    API:
    debug_overlay_init(parent) cria layer (idempotente, oculta)
    debug_overlay_set_enabled(bool) liga/oculta + move_foreground
    debug_overlay_is_enabled()
    debug_overlay_redraw() recreate per frame (sob lv_lock)
    Estrategia "recreate per frame": lv_obj_clean(layer) + criar
    ~4 l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
2026-06-06 feat(game): consolidacao Trilha-C — SD, room_layout, novos HALs e engine
    - Migra storage de NAND para microSD (sd_hal, SD_CS=47); remove storage_hal
    - Adiciona room_layout (header + gen + loader): layout de sala orientado a dados
    - Novos HALs: buzzer_hal, ws2812_hal; remove recovery e asset_store legados
    - Engine: defense_matrix + threat (MVP DDoS/Ransom/Propagacao)
    - Novas telas: screen_game_over, screen_hud
    - asset_loader/dialog_loader atualizados para leitura do SD (/sd/assets)
    - Ferramentas: build_sd_assets.py, gen_room_layout.py
    - sdkconfig/dependencies.lock sincronizados com IDF 6.0
    [asset_store.c, board_pins.h, button_hal.c]
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2026-06-06 feat(assets+ui+entity): pipeline de sprites individuais, layouts de sala e fix cJSON
    - Reescreve screen_empresa.c e screen_recepcao.c para modelo de sprites
    individuais: cada objeto e um PNG proprio com posicao exata (pivot
    bottom-center de posicao.txt), instanciado via room_layout_spawn().
    - Cria assets/layout/empresa.json e corrige recepcao.json com posicoes
    canonicas extraidas de posicao.txt e INTERACOES.txt (Aseprite sources).
    - Registra 41 assets em asset_registry.json (IDs 0-40) e regenera asset_ids.h.
    - Adiciona sprites empresa/ e recepcao/ (PNG individuais extraidos do vault).
    - Fix build: troca "json" por "espressif__cjson" em entity/CMakeLists.txt,
    adiciona entity/idf_compo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
    [CyberGame.kicad_sch, CyberGame_kicad.kicad_pcb, CyberGame_kicad.kicad_sch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]
2026-06-06 fix(ui+assets): furniture invisivel (dangling ptr) + frame NPC
    - room_layout_loader.c: corrige bug critico — lv_image_set_src usava &la.dsc
    (variavel de pilha), LVGL ficava com ponteiro dangling apos retorno da funcao.
    Adicionado asset_loader_get_dsc() que retorna ponteiro persistente do cache.
    - asset_loader.h/.c: adiciona asset_loader_get_dsc(type, id) -> const lv_image_dsc_t*
    - preparar_recepcao.py: corrige extracao dos frames NPC de row=2 (direita) para
    row=3 (frente/front-facing no formato LPC spritesheet).
    - Frames NPC_01, NPC_02, NPC_03 (IDLE e DIALOG) re-extraidos com row=3.
    - Instrucoes_Iniciais.md: documento de continuidade do projeto.
2026-06-09 feat(gameplay): menu servidor, tela DDoS, NFC e fix troca de HD
    - Tarefa amarela: fix troca de painel com HD em maos (!s_holding removido)
    - Menu servidor: prompt [A] em SERVIDOR_ESQUERDA e SERVIDOR_DIREITA; opcoes Backup->tarefa_amarela, WEB->tela_vermelha
    - Tela DDoS (screen_tarefa_vermelha): monitora fsm_get_attack_active(); fecha automaticamente ao mitigar
    - NFC: nfc_hal_init/start_scanning no engine; poll nao-bloqueante; loga UID real; fallback CARTA_BALANCEAMENTO
    - AREA_SERVIDOR: novo kind de gatilho para servidores (separado de AREA_TAREFA_AMARELA)
    [board_pins.h, button_hal.c, buzzer_hal.c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]
2026-06-09 fix(ui+engine+sim): tela servidor web com assets, alinhamento HDs e credenciais senha
    - screen_web_setor: integrado ao fluxo empresa (substitui placeholder tarefa_vermelha)
    - engine: NFC poll chama threat_mitigate() + screen_web_setor_on_carta() para sincronizar
    logica de jogo e estado visual; ddos/ransomware_start chamados a cada tick (idempotente)
    - screen_tarefa_amarela: corrige coordenadas SRV/STK de pivot (bc) para draw (top-left),
    evitando overflow dos slots de estoque abaixo dos 320px; radius=0 nos containers
    - screen_tarefa_verde: zera s_sel_user/s_sel_pass ao entrar em STEP_CONCLUIDA para forcar
    exibicao das credenciais salvas em vez dos indices obsoletos do array randomizado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
    [engine.c]
2026-06-11 fix(gameplay+nfc+ui): checkpoint pós-teste com público — 6 correções + WIP 06-09
    Correções da sessão 2026-06-10 (todas com entrada no CHANGELOG):
    - pause vira OVERLAY real: START não teletransporta mais o jogador pro
    spawn; empresa_destroy fecha overlays filhos (mata soft-lock invisível);
    ticks de overlay pausam durante o PAUSE
    - ransomware: modelo e UI alinhados — Isolamento <50% mitiga de verdade,
    >=50% CONGELA o timer (DEFESA_CONTIDO); Backup só funciona com a tarefa
    amarela do servidor concluída (HDs bons); reabrir a tela re-sincroniza
    - NFC: leitura durante ataque sem exigir tela aberta; fila drenada (carta
    fantasma); nfc_hal_init re-tenta handshake em vez de f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
    [calibracao.h]
2026-06-16 fix(nfc+gameplay+ui): ajustes de scan NFC, balanceamento e telas
    [engine.c, game_config.h, nfc_hal.c]
